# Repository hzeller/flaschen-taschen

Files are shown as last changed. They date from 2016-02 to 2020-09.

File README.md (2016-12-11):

Noisebridge Flaschen Taschen Project
====================================

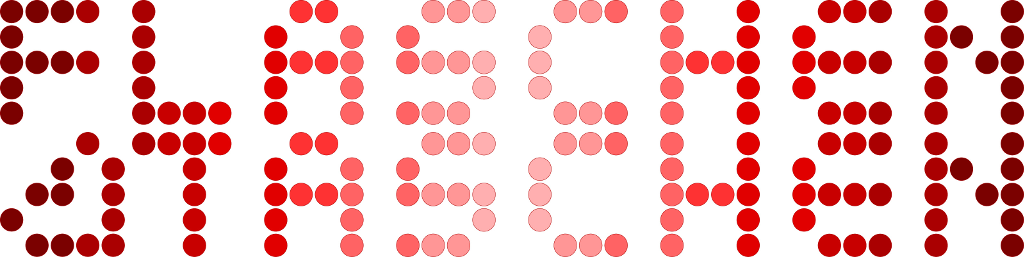
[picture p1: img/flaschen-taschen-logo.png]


Software and Raspberry Pi interface hardware for [FlaschenTaschen].

FlaschenTaschen is inspired by projects such as the [Muro de botellas]
or [MateLight]. A bunch of Noisebridgers have seen Mate Light in action
at [32c3] and got excited :)
So our Noisebridge interpretation of it has a German influenced name.

Unfortunately, in the US, bottle reuse is not at all a thing, so there
are no standardized crates with bottles you can buy.
So we use milk crates (which is a thing) and put common, clear 12oz (355ml)
bottles in (Mate, Corona,..) inside. Wrapped in aluminum foil, they
make nice pixels.

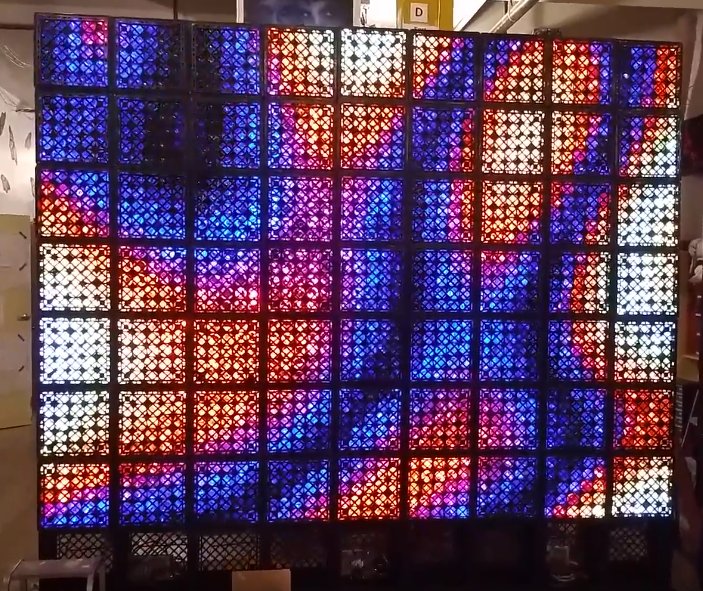
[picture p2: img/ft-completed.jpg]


How about watching [a movie](https://youtu.be/OEUFIpM10FE) ?

The set-up is 9 crates wide and 7 crates high for a total of
63 [crates (see wiring here)](./doc/wiring.md) with 25 'pixels' each
(this is what fits in our MakerFaire booth). 45x35 pixels or 1575 pixels total.
All operated by a Raspberry Pi that provides a [network API][protocols] to
update the display.

This is how it looks from the back:

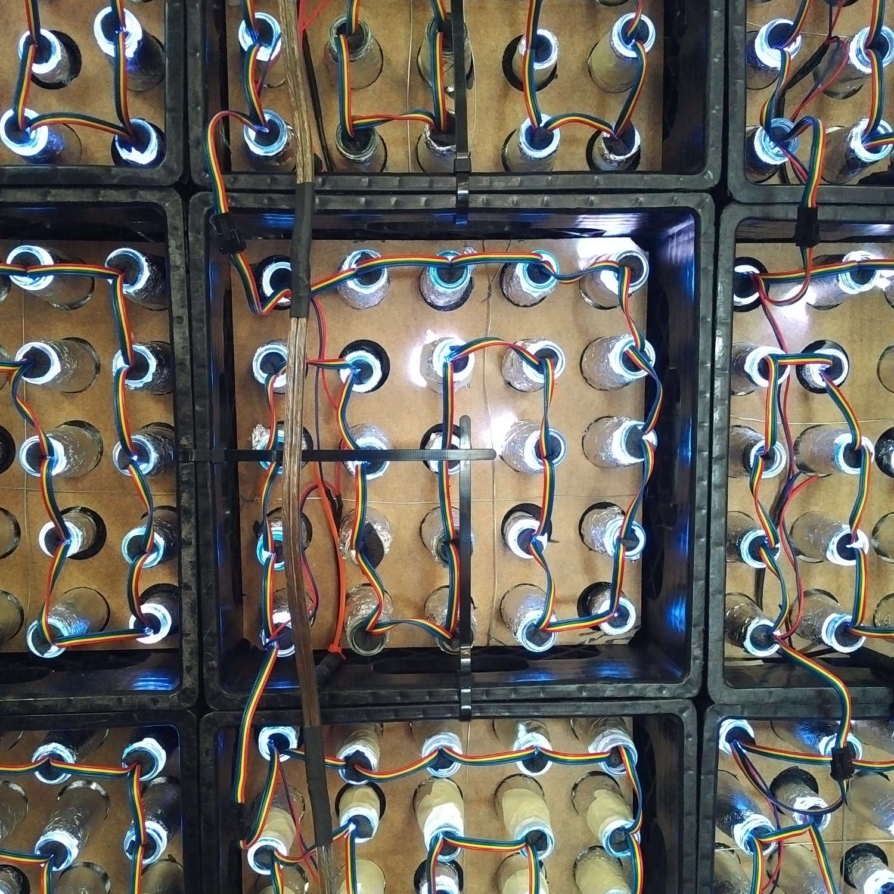
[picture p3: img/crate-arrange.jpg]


## Sending content to FlaschenTaschen

The [client](./client) directory contains some useful utilities such as
`send-text`, `send-image` or `send-video` that you might be interested in.

Also, the current development [VLC] natively supports the FlaschenTaschen
protocol if you want to send a video.

## Tutorial: start local server and create new clients

To develop visuals for the FlaschenTaschen display once it is ready, here you
can already play around writing software that updates the networked display.

#### 1. Check out the project

```bash
$ git clone --recursive https://github.com/hzeller/flaschen-taschen.git
$ cd flaschen-taschen
```

#### 2. Compile and run local server showing content in a Terminal

If you are not around Noisebridge to directly send images to the FlaschenTaschen
installation, then you can start your own FlaschenTaschen server that displays
the pixels as colored spaces in a terminal. Note, you need a fairly recent
terminal that can display 24 Bit color (Konsole can do that for a while, more
recent Gnome terminals as well. Also, newer xterms can do that as well. If you
are on a Mac, an iTerm2 version 3.x will work).

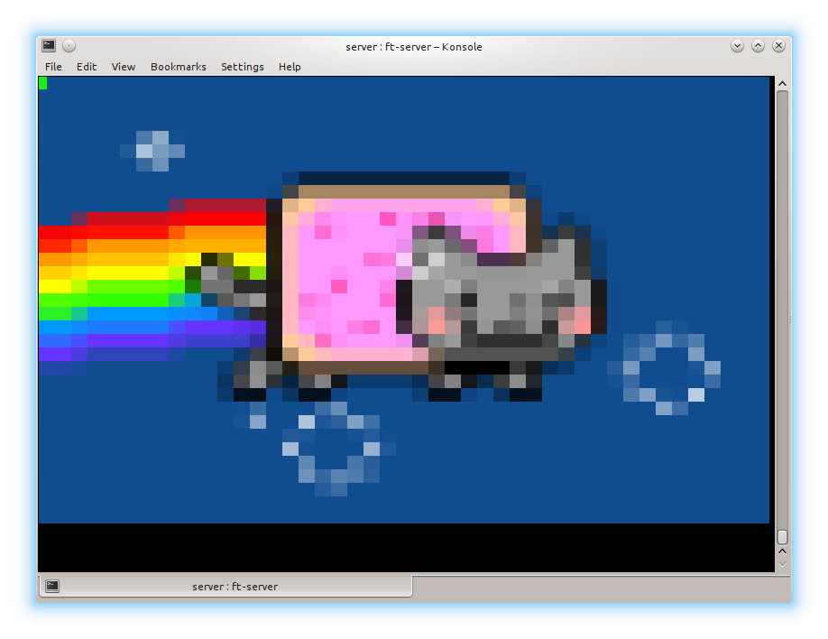
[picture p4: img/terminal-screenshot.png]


In one terminal, go to the [server/](./server) directory, compile the
terminal-based display and run it. Make sure to have it large enough to show
all pixels:

```
$ cd server
$ make FT_BACKEND=terminal
$ ./ft-server   #  this will now show a black 'screen'
```

(looks too big on screen ? Try adding the option `--hd-terminal`)

If you want to dig into details and understand the various server
implementations, check out the [server README](./server/README.md).

#### 3. Get started with the API
FlaschenTasachen provides a [network protocol](./doc/protocols.md), but there
are also client APIs available - the [api subdirectory](./api) is the best to
inspect here.

To get started with programming, go to the
[examples-api-use/](./examples-api-use) directory, compile the programs and
run it.

```
$ cd examples-api-use
$ make simple-animation
$ ./simple-animation localhost # <- network address of display.
```

Now go back to your terminal the `ft-server` is running and you'll see the
space-invaders animation!

Easiest to get started with the programming is
to read the [simple-example.cc](./examples-api-use/simple-example.cc) code,
then move on to [simple-animation.cc](./examples-api-use/simple-animation.cc).

If you want to implement the simple network protocol in another language
[check out the protocol description](./doc/protocols.md) or look at the
[C++ implementation](./api/lib/udp-flaschen-taschen.cc).

For some immediate fun, send a PPM image to your server. Since the server
already understands that format natively, you can unleash the usual
[netpbm] toolbox for image manipulation:

```
bash$ jpegtopnm myimage.jpg | stdbuf -o64k pnmscale -xysize 45 35 > /dev/udp/localhost/1337
```

For a tool that decodes images (including animated gifs), go to
the [client/](./client) sub-directory compile `send-image`
(`make send-image`, see
[Send-Image section in client/](./client/README.md#send-image) for needed
dependencies), then run
`./send-image -h localhost some-image.png` which reads images and
sends them to the FlaschenTaschen display.

## Related Software

There are various projects that create demos for F~T. Collecting links here.
Check out these repositories:

  * https://github.com/cgorringe/ft-demos Demos such as [plasma](./img/ft-completed.jpg), lines, quilt, ...
  * https://github.com/scottyallen/flaschenvnc VNC implementation:
   cast your screen to FlaschenTaschen
   ([like so](https://www.youtube.com/watch?v=s3pGp_Vf4Pk))
  * A [FlaschenTaschen VLC output](https://git.videolan.org/?p=vlc.git;a=commit;h=cf334f257868d20b6a6ce024994e84ba3e3448c3) by François Revol.
    It is already submitted upstream, but until it hits distributions, you have
    to [compile VLC from git](https://wiki.videolan.org/UnixCompile/). That VLC
    version is >= `3.0.0-git Vetinari`.
    Then `sudo make install ; sudo ldconfig` and run it like so:

   ```
    # Here, ft.noise is the hostname of the flaschen taschen display:
    $ vlc --vout flaschen --flaschen-display=ft.noise \
          --flaschen-width=45 --flaschen-height=35 \
          <video-filename-or-YouTube-URL>
   ```

## Connecting LED strips to the Pi

LED strips are controlled by a Raspberry Pi, connected via
a [custom level shifter](./hardware) for up to 16 strips
(of which we only need 9 for our installation right now).

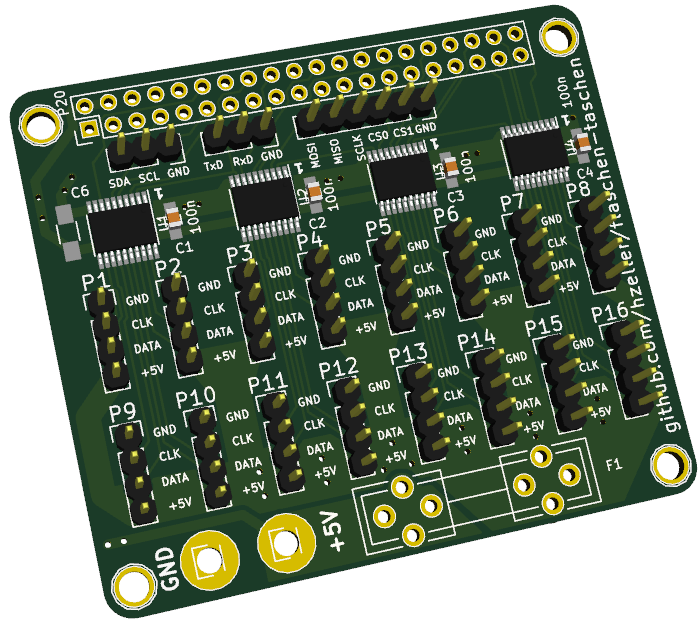
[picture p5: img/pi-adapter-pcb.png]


[FlaschenTaschen]: https://noisebridge.net/wiki/Flaschen_Taschen
[Muro de botellas]: http://www.zuloark.com/muro-de-botellas/
[MateLight]: https://github.com/jaseg/matelight
[RGB Matrix Adapter]: https://github.com/hzeller/rpi-rgb-led-matrix/tree/master/adapter/active-3
[32c3]: https://events.ccc.de/congress/2015/wiki/Static:Main_Page
[protocols]: ./doc/protocols.md
[netpbm]: http://netpbm.sourceforge.net/
[2025-video]: https://www.youtube.com/watch?v=hs8FoROzE4M
[7of9-video]: https://www.youtube.com/watch?v=Uc2-8ntcEpY
[VLC]: https://www.videolan.org/

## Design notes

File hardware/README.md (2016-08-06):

Hardware
========

## Connecting LED strips to the Pi

LED strips are controlled by a Raspberry Pi, connected via
a custom level shifter that first has been developed for FlaschenTaschen
but is now broken out as [separate Spixels PCB and library][spixels].

This adapter to the Raspberry Pi can support up to 16 SPI LED strips (e.g. WS2801 or APA102) at once.

&nbsp;&nbsp;&nbsp;&nbsp;&nbsp;


## Pi Mounting Plate

We have the Pi in a separate crate together with one of the power supplies. It is
held in place with zip-ties through the holes of the crate using this
laser-cut mounting plate. To be easily modifyable,
[it is written in PostScript](./pi-mounting-rig.ps) and can be converted to a
[DXF file](./pi-mounting-rig.dxf) (a typical input to laser cutters)
with the Makefile.

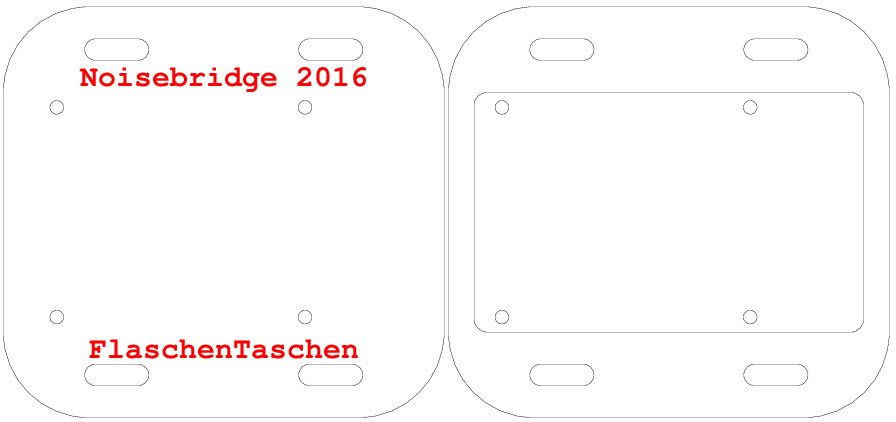
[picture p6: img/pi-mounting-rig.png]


[spixels-hardware]: https://github.com/hzeller/spixels/tree/master/hardware
[spixels]: http://spixels.org/

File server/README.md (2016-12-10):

Server implementation
=====================

The server implements the [network protocol](../doc/protocols.md) so that
it is easy to interface with the display over the network.

## Regular Flaschen Taschen server

For the actual Flaschen Taschen display, simply build with

```
  make FT_BACKEND=ft
```

(Note, this needs the http://spixels.org library, which is included as git
sub-module. So you have to `git clone --recursive` the flaschen-taschen repo).

These are the options

```
usage: ./ft-server [options]
Options:
        -D <width>x<height> : Output dimension. Default 45x35
        --layer-timeout <sec>: Layer timeout: clearing after non-activity (Default: 15)
        -d                  : Become daemon
```

```bash
 # Run as root.
 sudo ./ft-server -d
```

To change resolution and composition of the actual display, you have to
manually adapt the code in main.cc (look for `display.AddColumn()`) - to
choose type of LED strip and to which SPI port on the spixels hardware they
are connected to.

The server has to be started as root as it has to access and initialize the
GPIO pins, but it drops privileges to uid=daemon, gid=daemon after that is done.

Stopping ? Kill the hard way `sudo killall ft-server`.

*This assumes to be running on the Raspberry Pi* as it needs to access the
[GPIO pins](../hardware) to talk to the LED strips.



## Testing setups

If you are not at Noisebridge right now but want to hack on applications
that use the display, you can use different ways to visualize the output with
the following applications.

These test-setups allow to simulate the display in its full resolution
supporting the same protocol.

### Terminal

On any development machine with a somewhat decent terminal that allows for
24Bit [ANSI color][term-color] (konsole, xterm or gnome-terminal on Linux;
xterm/X11 or iTerm2 >= 3.0 on OS X), this `ft-server` allows to display the
result in a terminal.

```bash
  # Build with
  make FT_BACKEND=terminal
```

```bash
  # Then run (and optionally pass the desired resolution)
  ./ft-server -D45x35
```

This also has an option to have a more compact representation - the resolution
is twice as high which allows to display it on smaller terminals. However,
it depends a bit more on your terminal to properly display UTF-8 characters:

```bash
./ft-server -D45x35 --hd-terminal
```

Regular terminal             | With `--hd-terminal` Option   |
-----------------------------|-------------------------------|
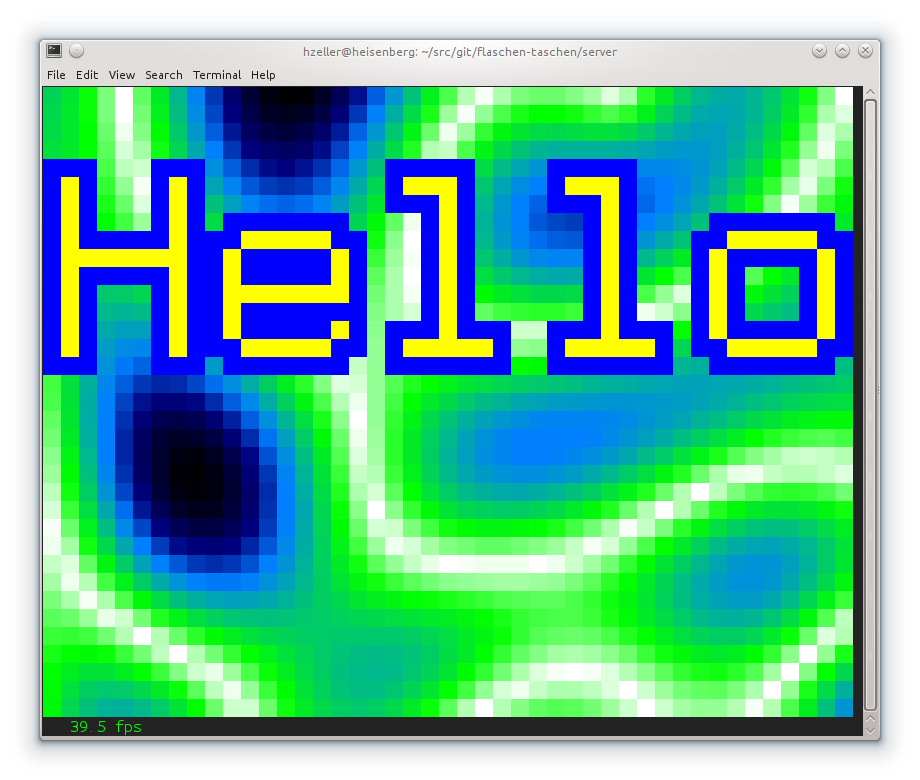
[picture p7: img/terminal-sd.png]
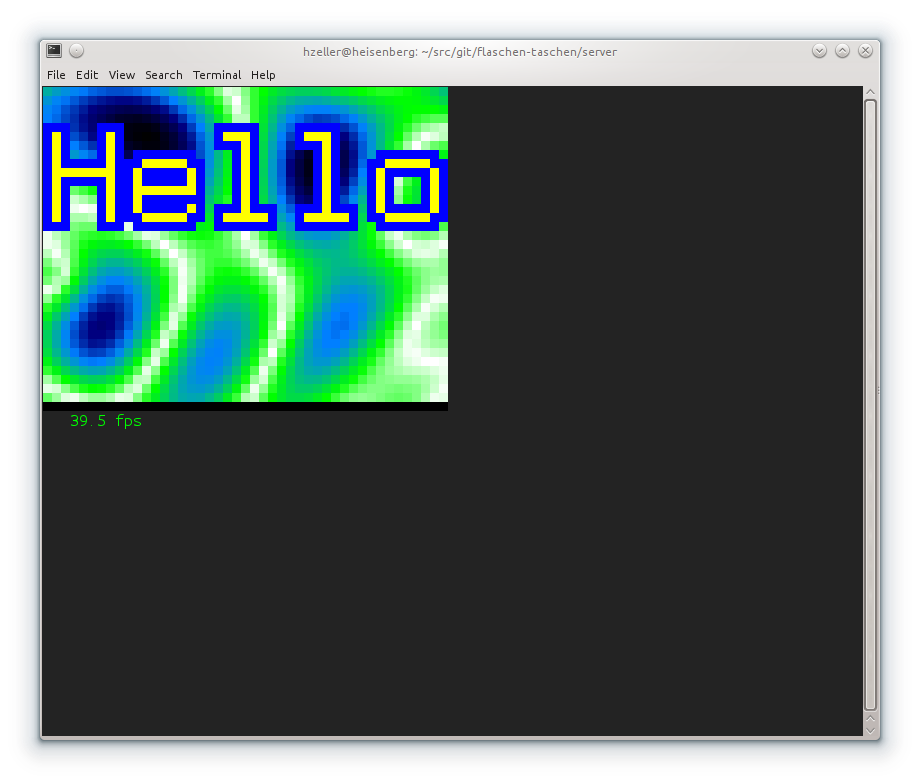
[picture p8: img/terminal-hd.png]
  |    |


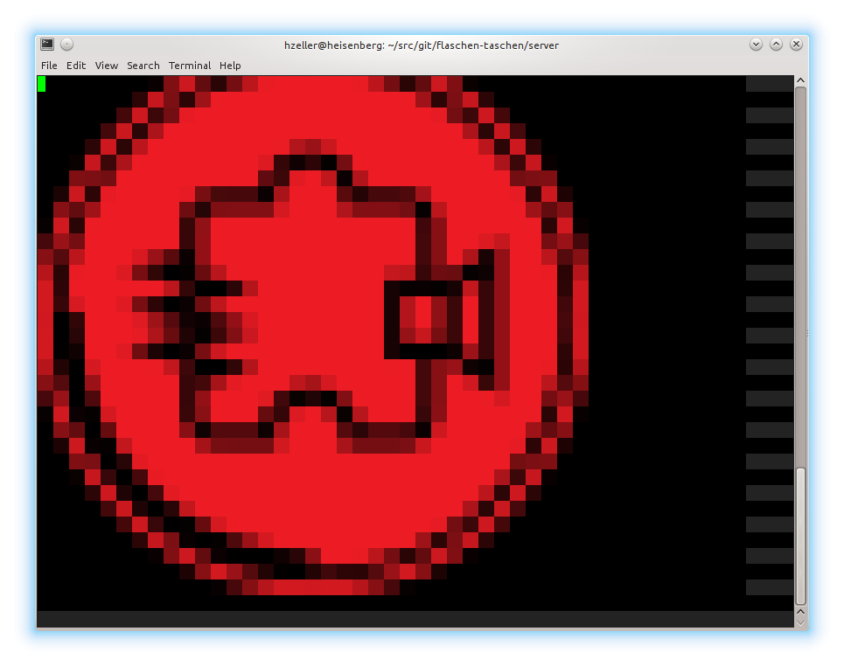
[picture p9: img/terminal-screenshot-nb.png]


### RGB Matrix Panel Display

If you have an [RGB matrix][rgb-matrix] connected to a Pi, you can run that
as Flaschen Taschen backend:

```bash
  make FT_BACKEND=rgb-matrix
```

Run it and pass the usual [rpi-rgb-led-matrix flags][led-flags]. Here, we have
a set-up with three parallel chains of 5 32x32 displays each
```bash
  sudo ./ft-server --led-chain=5 --led-parallel=3 --led-rows=32
```

If you pass the option `-d`, it will run as daemon in the background.

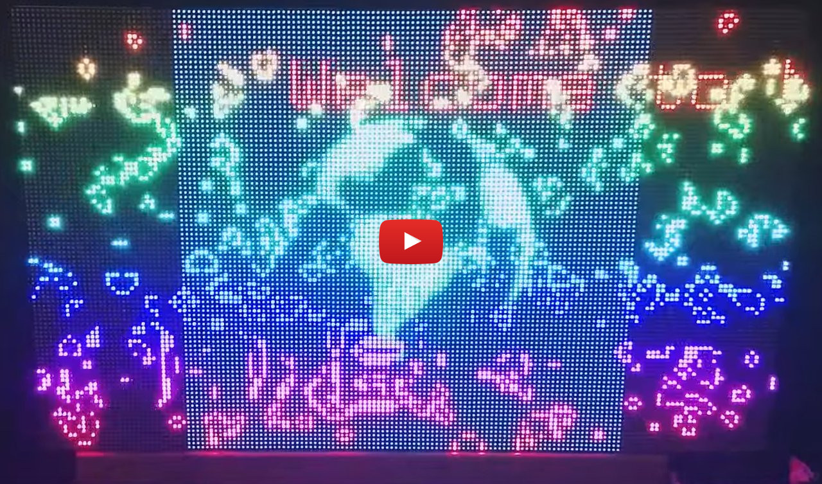
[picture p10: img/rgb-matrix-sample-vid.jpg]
RGB-MatrixImpl
[](https://www.youtube.com/watch?v=XeJBcNevuJE)
(this is 160x96 display with the `--led-chain=5 --led-parallel=3`).

This runs on a Raspberry Pi; see the
[documentation in the RGB-Matrix project][rgb-matrix]

[rgb-matrix]: https://github.com/hzeller/rpi-rgb-led-matrix
[ft-rgb-vid]: ../img/rgb-matrix-sample-vid.jpg
[term-color]: https://gist.github.com/XVilka/8346728
[led-flags]: https://github.com/hzeller/rpi-rgb-led-matrix#changing-parameters-via-command-line-flags

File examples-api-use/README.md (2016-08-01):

Getting started with the API
============================

This gives you some starting point to get started with the API.

### Network destination

Your programs connect to the display over the network. If you give `NULL`
as the location in the `OpenFlaschenTaschenSocket()` API call, the
hostname is determined from the environment variable `FT_DISPLAY`. If that
is empty, it falls back to the Noisebridge installation `ft.noise`.

So if you are working with a particular instance of FlaschenTaschen (e.g.
a [local terminal](../server/README.md#terminal)), just set the environment
variable for ease of playing.

```
export FT_DISPLAY=localhost
```

## Example Code

Coding content for FlaschenTaschen is trivial as you just need to send it UDP
packets with the content. Any language of your choice that supports networking
will do.

For C++, there is a simple implementation of such a 'client display', the
[simple-example.cc](./simple-example.cc) helps to get started.

```c++
#include "udp-flaschen-taschen.h"

#define DISPLAY_WIDTH  45
#define DISPLAY_HEIGHT 35

int main() {
    // Open socket and create our canvas.
    const int socket = OpenFlaschenTaschenSocket("ft.noise");  // hostname.
    UDPFlaschenTaschen canvas(socket, DISPLAY_WIDTH, DISPLAY_HEIGHT);

    const Color red(255, 0, 0);
    canvas.SetPixel(0, 0, red);              // Sample with color variable.
    canvas.SetPixel(5, 5, Color(0, 0, 255)); // or just use inline (here: blue).

    canvas.Send();                           // Send the framebuffer.
}
```

Next step, try a [simple-animation.cc](./simple-animation.cc)
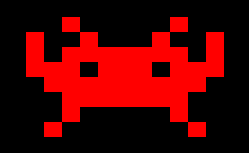
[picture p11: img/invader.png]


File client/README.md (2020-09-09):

Flaschen Taschen Clients
========================

Useful utilities to send content to the FlaschenTaschen installation.

This directory provides:
  * `send-text` binary, that prints a static or scrolling text.
  * `send-image` binary, that reads an arbitrary image (including
    animated *.gifs), scales it and sends to FlaschenTaschen.
  * `send-video` binary, that reads an arbitrary video, scales it and
    sends to FlaschenTaschen.

### Network destination

The clients connect to the display over the network. The
default hostname is pointing to the installation within Noisebridge
(currently `ft.noise`).

You can change that with commandline flags (e.g. `send-text`, `send-image`,
and `send-video` all have a `-h <host>` option) or via the environment
variable `FT_DISPLAY`.

So if you are working with a particular instance of FlaschenTaschen (e.g.
a [local terminal](../server/README.md#terminal)), just set the environment
variable for ease of playing.

```
export FT_DISPLAY=localhost
```

### UDP Size

The images are sent via UDP, and if the size does not fit in a single packet,
it will be split up into multiple stripes, so even large screens are supported.

The default assumed size of a maxium UDP packet is
65507 bytes (65535 - IP and UDP header), but note that on some operating
systems (notably OSX), the default allowed size is smaller. If you try to send
a large image or video and you get error messages, this might be the reason.

To fix: Either tell the client tool such as `send-video` to use a smaller
UDP size with the environment variable `FT_UDP_SIZE`. E.g.

```
FT_UDP_SIZE=8000 ./send-video -g320x200 ...
```

This will split the image into more stripes, so requies more network packets,
but it will work.

Or, if your operating sytem allows, set a larger limit. On OSX this would be:

```
sudo sysctl -w net.inet.udp.maxdgram=65535
```

## Send-Text

### Compile
```bash
make
```

### Use
```
usage: ./send-text [options] <TEXT>
Options:
        -g <width>x<height>[+<off_x>+<off_y>[+<layer>]] : Output geometry. Default 45x<font-height>+0+0+1
        -l <layer>      : Layer 0..15. Default 1 (note if also given in -g, then last counts)
        -h <host>       : Flaschen-Taschen display hostname.
        -f <fontfile>   : Path to *.bdf font file
        -s<ms>          : Scroll milliseconds per pixel (default 60). 0 for no-scroll.
        -O              : Only run once, don't scroll forever.
        -S<px>          : Letter spacing in pixels (default: 0)
        -c<RRGGBB>      : Text color as hex (default: FFFFFF)
        -b<RRGGBB>      : Background color as hex (default: 000000)
        -o<RRGGBB>      : Outline color as hex (default: no outline)
        -v              : Scroll text vertically
```

Sample
```bash
./send-text -f fonts/6x10.bdf "We ♥ Flaschen Taschen"

# Or coordinated horizontal and vertical messages
./send-text -h localhost "♥Flaschen" -f fonts/5x5.bdf -s 60 -g 45x35+0+15+3 & ./send-text -h localhost "Taschen " -f fonts/5x5.bdf  -v  -s 60 -g 45x35+20+0+2 && fg

# Or, how about showing the time
while : ; do sleep 1 ; ./send-text -f fonts/9x18.bdf -s0 `date +%H:%M` ; done
```

Text has a default layer of 1, so it is hovering above the background image.
If you don't want that, you can explicitly set it as last value in the geometry
specification.

If you add a `-o` color, then the font gets an outline of that given color,
which you can use to create a contrast for the font.
## Send-Image

### Compile
```bash
# Need some devel libs
sudo apt-get install libgraphicsmagick++-dev libwebp-dev
make send-image
```

### Use
```
usage: ./send-image [options] <image>
Options:
        -g <width>x<height>[+<off_x>+<off_y>[+<layer>]] : Output geometry. Default 20x20+0+0+0
        -l <layer>      : Layer 0..15. Default 0 (note if also given in -g, then last counts)
        -h <host>       : Flaschen-Taschen display hostname.
        -s[<ms>]        : Scroll horizontally (optionally: delay ms; default 60).
        -C              : Just clear given area and exit.
```

Essentially just send the FlaschenTaschen display an image over the network:

```
./send-image -g10x20+15+7 some-image.png
```

Image will be scaled to the given size (here 10x20) and shown
on the FlaschenTaschen display at the given offset (here 15 pixels x-offset,
7 pixels y-offset).

The program exits as soon as the image is sent unless it is an animated gif in
which case `send-image` keeps streaming until interrupted with `Ctrl-C`.

If you want to scroll a long image accross the display, use the `-s` option. In
this case, only the height is scaled to the display height and the image is
scrolled infinitely over width.

Let's try this with an example image:

```
./send-image -s ../img/flaschen-taschen-black.ppm
```

## Send-Video

This utility here is a simple video output without sound.

The upstream VLC [now has FlaschenTaschen support][vlc-commit] natively, so this
might be the better option these days (currently, you have to compile it
from source to get this bleeding edge).

### Compile
```bash
# Need some devel libs
sudo apt-get install libavcodec-dev libavformat-dev libswscale-dev
make send-video
```

### Use
```
usage: ./send-video [options] <video>
Options:
        -g <width>x<height>[+<off_x>+<off_y>[+<layer>]] : Output geometry. Default 20x20+0+0
        -h <host>          : Flaschen-Taschen display hostname.
        -l <layer>         : Layer 0..15. Default 0 (note if also given in -g, then last counts)
        -v                 : verbose.
```

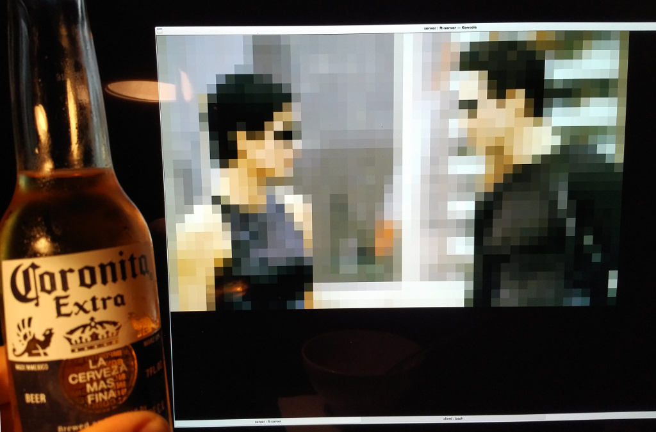
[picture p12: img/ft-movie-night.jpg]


[vlc-commit]: https://git.videolan.org/?p=vlc.git;a=commit;h=cf334f257868d20b6a6ce024994e84ba3e3448c3

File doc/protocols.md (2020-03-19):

Protocols
=========

To make it simple to illuminate the matrix, there is a simple network protocol
that allows to stream images to the FlaschenTaschen installation (we used to
support some other protocols natively, but they moved out to be done via a
dedicated bridge).

## Flaschen Taschen Protocol

Receives **UDP** packets with a raw [PPM file][ppm] (`P6`) on port 1337 in a
single datagram per image.
A ppm file has a simple text header followed by the binary RGB image data.

FlaschenTaschen has a special feature that allows you to choose the offset the
image is displayed on the screen in (x,y) direction and as a layer.

To provide this additional information without violating the PPM file standard,
there is a special comment that you can put in the header (because `#`-comments
are allowed in the PPM header) that describe the offset of the image on the
display in X, Y and Z-direction (=layer).

The comment must start with exactly **`#FT:`**. In the following example,
a 10x10 image is sent with the (x,y) offset of (5,8), the layer (z-offset)
is 13; the full UDP packet combining header and data looks like this:

------

```
P6     # PPM binary Portable PixMap magic number
10 10  # width height (decimal, number in ASCII)
#FT: 5 8 13
255    # values per color (fixed). After newline, 10 * 10 * 3 bytes RGB data follows
```
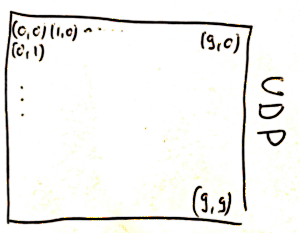
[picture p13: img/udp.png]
 (300 bytes RGB data)<br/>

------

(the header is followed by the binary image data, three bytes per pixel RGB, so in this case 10x10x3 = 300 bytes)

There is an alternative way to provide the offset by appending it at the _end_ of
the image data in a similar format like the header because that is sometimes
easier to do depending on your implementation.
Appending it at the end makes it also backward compatible with
standard PPM (as PPM just ignores additional data at the end).

Here the same 10x10 image with (header + data + optional footer). The footer is
similar formatted like the header: decimal numbers, separated by space).
End-of-line comments in the header/footer are allowed with `#` character. So
the full UDP packet combining header, data and footer looks like this:

------

```
P6     # PPM binary Portable PixMap magic number
10 10  # width height (decimal, number in ASCII)
255    # values per color (fixed). After newline, 10 * 10 * 3 bytes RGB data follows
```
 (300 bytes RGB data)<br/>
```
5      # optional x offset
8      # optional y offset
13     # optional z offset.
```

------

The optional offset determines where the image is displayed on the
Flaschen Taschen display relative to the top left corner (provided in the
[remote Flaschen Taschen class][cpp-client-api] as a `SetOffset(x, y, z)` method).

### Offsets, how do they work ?

The **(x,y) offset** allows to place an image at an arbitrary position on the
screen - good for animations or having non-overlapping areas on the screen.

The **z offset** represents a **layer** above the background. Zero is the
background image, layers above that are overlaying content if there is a
color set (black
in layers not the background are regarded transparent).
That way, it is possible to write games simply (consider typical arcade games
with slow moving background, a little faster moving middelground and a fast
moving character in the front. This allows for full screen sprites essentially).

Or you can overlay, say a message over the currently running content.
The nice thing is is that you don't need to know what the current background
is - a fully networked compositing display essentially :)
This allows display access for independent people on the network, right the
way we use it at Noisebridge.

Note: layers above the background (z=0) will auomatically turn transparent again
if they stick around for a while without being updated (that is
the `--layer-timeout` flag to the server).

### Send images right from the command-line

Since the server accepts a standard PPM format, sending an image is as
simple as this; you can make use of the convenient pnm-tools right from your
command line, how cool is that ?

```bash
# This works in the bash shell providing the pseudo-files /dev/udp/host/port
bash$ jpegtopnm color.jpg | stdbuf -o64k pnmscale -xysize 20 20 > /dev/udp/ft.noise/1337
# replace 'ft.noise' with 'localhost' if you have
# a locally running server, e.g. terminal based
```

If you're not using `bash`, then the `/dev/udp/...` path won't work, then
you can use the network-swiss army knife `socat`
```
$ jpegtopnm color.jpg | stdbuf -o64k pnmscale -xysize 20 20 | socat -b64000 STDIO UDP-SENDTO:ft.noise:1337
```

#### Implementations
You find some tools in the [`client/` directory](../client) to directly send
content to the server.

For the API level, there are a couple APIs provided in the [`api/`](../api)
directory, that let's you get right into it:

 * [C++ API][cpp-client-api]
 * [Python API][py-client-api]

For instance, the [FlaschenTaschen demos] by Carl are using the C++ API.

There is a [FlaschenTaschen VNC implementation](https://github.com/scottyallen/flaschenvnc) by Scotty. Scotty also wrote a server implementation for the ESP8266
that runs LED strips in the [Noise Square Table] and the Noisebridge library
shelves.

To watch videos, there is now a [FlaschenTaschen VLC output](https://git.videolan.org/?p=vlc.git;a=commit;h=cf334f257868d20b6a6ce024994e84ba3e3448c3) by François Revol available (until it hits distributions, you have to [compile VLC from git](https://wiki.videolan.org/UnixCompile/)).

### Network address of Installations
Within Noisebridge, the hostname of the large 45x35 pixel installation
is `ft.noise`.
The smaller 25x20 display is called `ftkleine.noise`.
Then there are pixel strip implementations for
the bookshelves with hostname `bookcase.noise` and
the [Noise Square Table], hostname `square.noise`.

#### Notes
For huge displays (more than 21k pixels) we run into UDP packet size limit of
roughly 64k. In that case, you need to send several tiles of the image and use
the offset feature to place them on the screen.
(We might consider adding a TCP protocol for these cases).

Note, this is _not_ an issue with the large FlaschenTaschen installation at
Noisebridge (1575 pixels) as it requires less than 8% of the UDP limit. But it
could be an issue with huge assemblies using an
[RGB Matrix](../server#rgb-matrix-panel-display) with many small LEDs.

[ppm]: http://netpbm.sourceforge.net/doc/ppm.html
[cpp-client-api]: ../api/include/udp-flaschen-taschen.h
[py-client-api]: ../api/python/flaschen.py
[Noise Square Table]: https://noisebridge.net/wiki/Noise_Square_Table
[FlaschenTaschen demos]: https://github.com/cgorringe/ft-demos

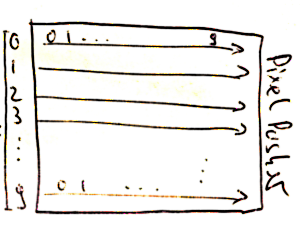
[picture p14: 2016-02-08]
img/pixelpusher.png

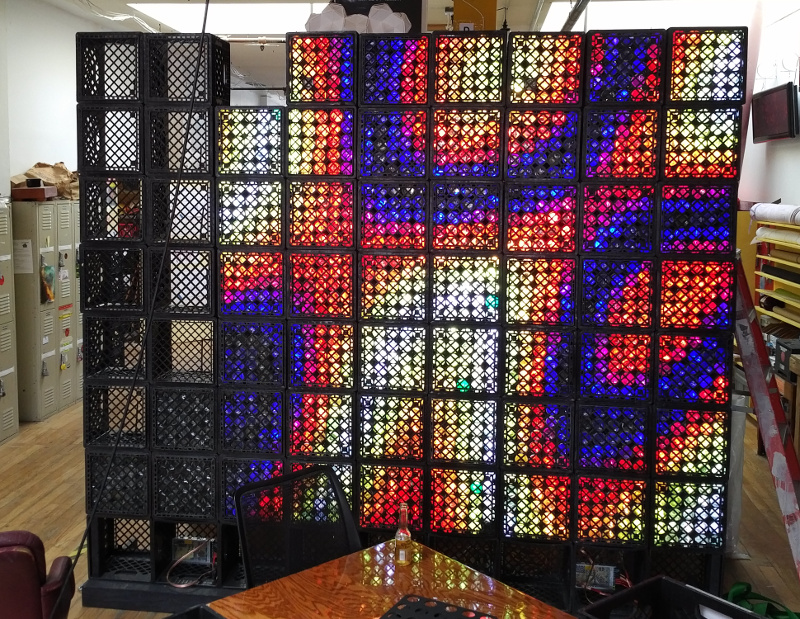
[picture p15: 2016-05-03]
img/ft-work-in-progress.jpg

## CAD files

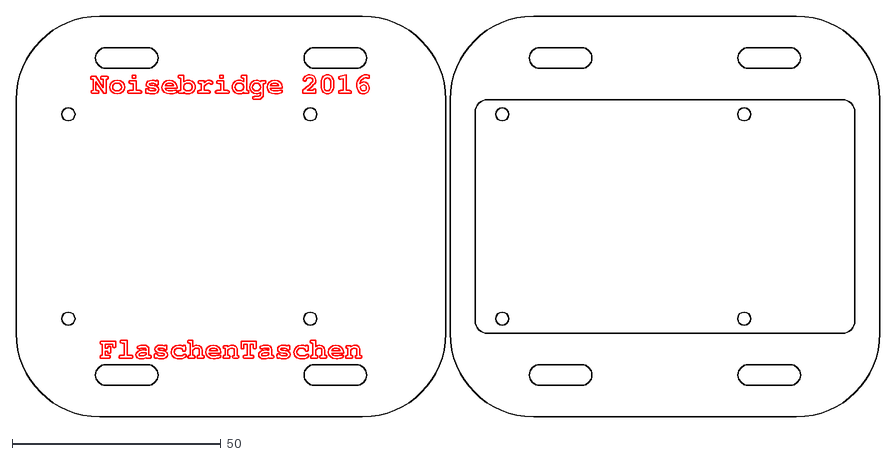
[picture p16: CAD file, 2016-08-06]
hardware/pi-mounting-rig.dxf
207.0 x 96.0

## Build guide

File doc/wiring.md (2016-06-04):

Wiring the crate
================

Looking from the back, the crate has the incoming data on the left bottom,
exit top left. We also have one power barrel connector on each crate, as well on the bottom
left.

The wiring is in a zig-zag pattern through the crate such that we reach the goal having
the incoming/outgoing cables at the right place.

## Tracing through the Crate

Here some schematic representation - Stars represent the bottle-necks, the arrows
the wiring between them. You can retrace that in the picture below.

```
  |  outgoing. 4-position female connector.
+-|---------------------+
| * <- * <- * <- * <- * |
|                     ^ |
| * -> *    * -> *    * |
| ^    v    ^    v    ^ |
| *    *    *    *    * |
| ^    v    ^    v    ^ |
| *    *    *    *    * |
| ^    v    ^    v    ^ |
| *    * -> *    * -> * |
+-|---------------------+
  |
  | Incoming. 4 position male connector.
```

## The power connection

The LED power inputs are long loose cables on both ends of the strip that we
combine and solder to a barrel-jack receptacle pig-tail, see image below.
Make sure to thread the wires from the LED _under_ the data wiring between the bottles.

As a preparation for soldering, the pigtail needs to be shortened by about 10cm (4 inches),
the LED power cables roughly by 6cm (2.5 inches) to not have too much slack. When removing outer
insulation from the pig-tail, make sure to not injure the insulation of the inner cables.

You don't have to unfold the whole LED strip or put it in the box to solder on the
power pigtail. Just do the whole process directly on the bundle of LEDs, it saves a lot of
time. The below images have the crate in the background for illustration purposes.

Uninsulate about 1 inch of the wires going to the LEDs and twist together the red
and blue ones separately. Put a ~1 inch of heat-shrink tubing up each pair now, so that we don't
forget that - move it up enough that it won't heat up while we solder.

Put about 1.5 inches of heat-shrink tubing wide enough to fit around the pigtail insulation now
as well - we need that later to tie everything together.

Now, uninsulate as well the wires on the pigtail about 1 inch. Now make a
[Lineman splice] with the corresponding wire-pair from the
LEDs (colors: red with red, white (pigtail) with blue (LED)). Solder the splice (it giving the
twisting, the whole length of the splice is now probably about 1/2 inch).

(If anything: remember the [Lineman splice] - it is a very useful skill!).

Move the heat-shrink that we have parked on the LED cables to each connection and shrink with
quick movements with a lighter (or, if that is not at hand, with the hot-air gun).

  Splice before solder.  |  Heat Shrunk.           | Heat Shrink overall.      | Done.
-------------------------|-------------------------|---------------------------|--------------------------|
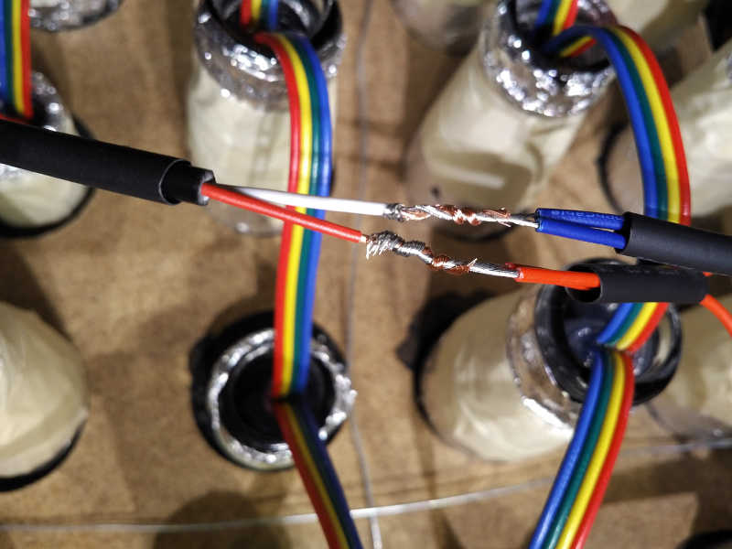
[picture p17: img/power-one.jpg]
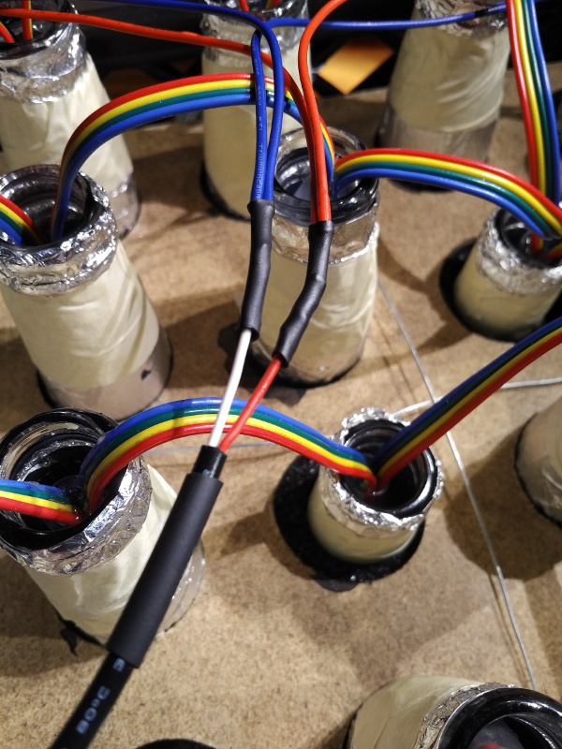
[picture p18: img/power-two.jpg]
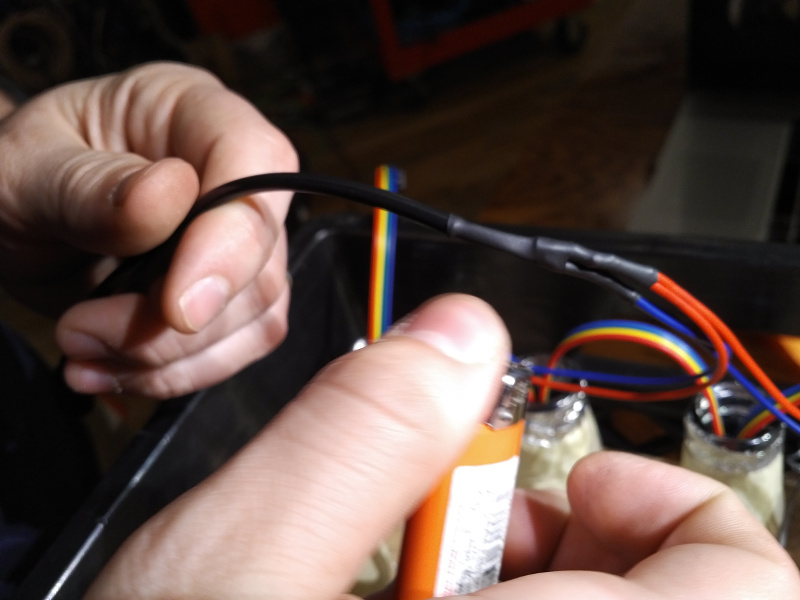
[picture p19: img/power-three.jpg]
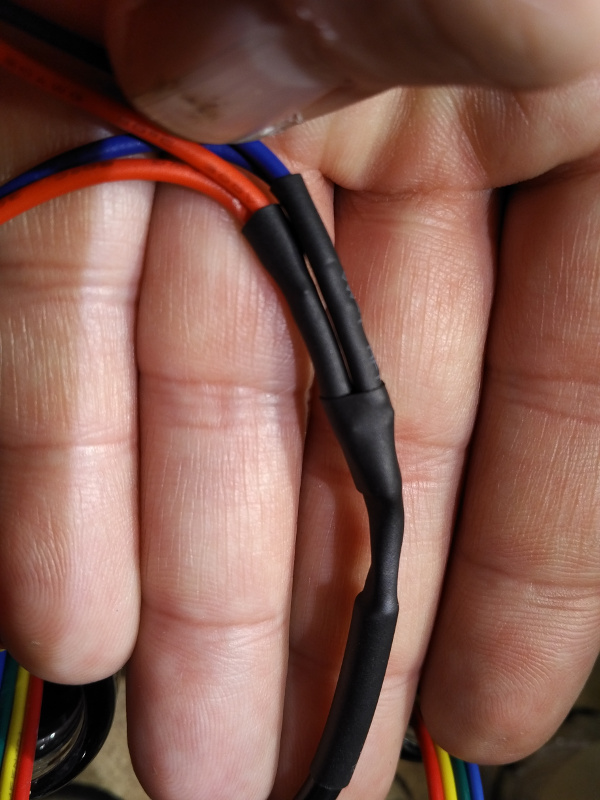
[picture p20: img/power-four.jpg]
||||

Let it cool so that it is hand-warm again. Then move the heat-shrink parked on the pigtail
up so that it squeezes the other heat-shrunk connection together and on the other end covers the
outer insulation of the pigtail. Shrink that. Now we have a sturdy connection.

(Use the heat shrink of which we have large rolls in the electronic area on the
left side on the shelf).

The Pigtail should be cable-tied to the crate for now. Later on we might want
a stress relief flap screwed to the wood ?

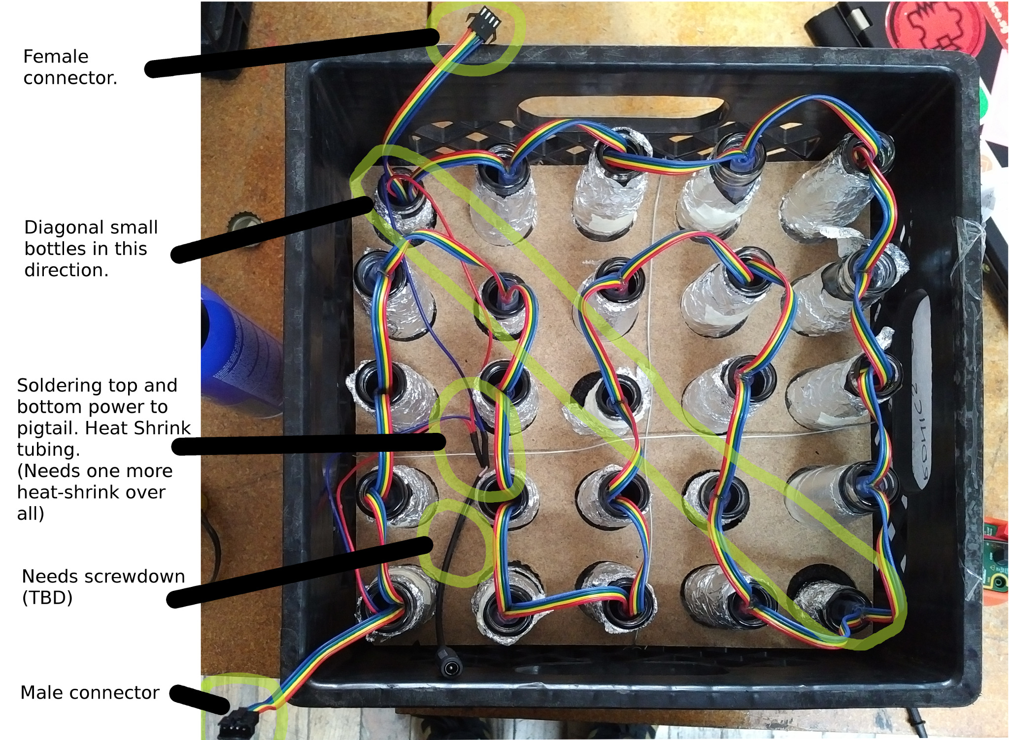
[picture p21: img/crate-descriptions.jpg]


## The Result

This is how it looks when it is all connected within the final display: the
data connectors are chained from crate to crate. A separate spine with power
is supplying 5V to each crate individually.

Due to the cabeling, this is also fault tolerant: if power gets disconnected
on one crate, it will be powered, through GND/+5V line of the data cables, from
the two adjacent crates above and below.

All data and power connectors run up on the left side, so it is very simple to
stack crates without much thinking when moving the installation. The cable-ties
to secure the crates are the reusable kind.



[Lineman splice]: http://makezine.com/2012/02/28/how-to-splice-wire-to-nasa-standards/

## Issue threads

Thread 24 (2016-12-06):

Problem flaschen taschen with RGB matrix

ffqqtv, 2016-12-06:
Thanks about flaschen-taschen library ! it is great . Now , i have 9 module RGB matrix ( 64x32) connecting Pi 3 , I am using flaschen-taschen library to send image and video , but I do not know how to adjust --led-rows=<rows> --led-chain=<chained> --led-parallel=<parallel> --led-brightness=<percent> -C
https://youtu.be/XVejSbku9Nc

hzeller, 2016-12-10:
You have 6 LED panels in a row, so you want --led-chain=6. The 32x32 pixel will already work with the default settings (--led-rows=32 --led-parallel=1).

hzeller, 2016-12-10:
Also, until a few minutes ago, you also had to explicitly make sure to set the geometry on the server side with `-D64x32`. If you do a fresh `git pull`, this will now be automatic.

Closed 2017-07-30.

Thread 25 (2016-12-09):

extending the chain lenth

alexdisoza007, 2016-12-09:
hi

Great job !.. I'm working  on this project and not able to extend the chain length, (in  rpi-rgb-led-matrix used -c option to extend the chain length) , how to extend the chain length in this project.

Thanks
Alex

hzeller, 2016-12-10:
You mean you are using it with the led matrix ? Try `--led-chain` instead of `-c`

alexdisoza007, 2016-12-10:
Hi,
I tired with this command `./send-text -h localhost --led-chain=2 --led-rows=32 -f fonts/9x18.bdf "flaschen taschen"` but this error popup `./send-text:` invalid option -- '-'`

Thanks
Alex

hzeller, 2016-12-10:
the `--led-chain` you need to give on the **server**, as that is running the LED. That server then provides the display you send stuff with clients such as send-text.

The send-text only needs the right size of your display  with `-g192x32` for instance.

alexdisoza007, 2016-12-10:
Hi.
Its working , but it is only using only 48x32, but mine is 64x32.

hzeller, 2016-12-10:
Did you make sure to set the resolution in the client program so that it knows how big of a framebuffer to send ?
```
 ./send-text -g64x32 ...
```

alexdisoza007, 2016-12-10:
Yes, its  is -g64x32 only , `./send-image -g64x32 -h localhost ../img/spixels-video.jpg`.

alexdisoza007, 2016-12-10:
yes , its only -g64x32, ./send-image -g64x32 -h localhost `../img/spixels-video.jpg`
[https://www.youtube.com/watch?v=MgZdQJVqTzA&feature=youtu.be](url)

alexdisoza007, 2016-12-10:
Hi,
I got out of that issue by using `-D 64x32` on server side. Thanks for your support.

Thanks
Alex

Closed 2016-12-10.

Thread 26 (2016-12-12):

Not able to display small letters in newly committed code

alexdisoza007, 2016-12-12:
Hi,
In text example program , If I give text in small letters it is displaying in capital letters. Is their any other ways to display small letters?
If I provide more than one text by pipe lining with different offset i am getting flickering problem ,Is it is due to power issue ? please do find the attach  link
[https://www.youtube.com/watch?v=iqwcEEiQQgU&feature=youtu.be](url)

Thanks
Alex

hzeller, 2017-07-30:
I suspect you used a font that didn't have lower case characters ?

If you send multiple text on the same layer, they will be 'fighting' each other as you replace the previous pixels with the new pixels. Try sending them on a different layers.

Closed 2017-08-22.

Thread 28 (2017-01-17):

Issue compiling

crablab, 2017-01-17:
```
`ft-thread.o: In function `ft::Mutex::WaitOnWithTimeout(pthread_cond_t*, int)':
ft-thread.cc:(.text+0x290): undefined reference to `clock_gettime'
collect2: ld returned 1 exit status
Makefile:76: recipe for target 'ft-server' failed
make: *** [ft-server] Error 1
`
```

hzeller, 2017-01-17:
What is the Linux distribution you're compiling it on ? On older installations, you might need to add `-lrt`  to the `LDFLAGS+=-lpthread` line in the Makefile.

crablab, 2017-01-17:
Ubuntu 16.10
I'll try that

hzeller, 2017-07-30:
I suspect that worked out ?

crablab, 2017-07-30:
I think it did, thanks!

Closed 2017-07-30.

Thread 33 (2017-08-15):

flaschen-taschen Full screen Image

beikimajid, 2017-08-15:
According to https://github.com/hzeller/rpi-rgb-led-matrix/issues/372,
(My image and my led screen are  384x96)

I use (**./ft-server**) and  -g  parameter (./send-image -g384x**96**+0+0 some-image.png)
_Result :         Attempting to send image larger than fits in a UDP packet (110623 > 65507 bytes)_

I use (**./ft-server**) and  -g  parameter (./send-image -g384x**54**+0+0 some-image.png)
_Result :        It does not show anything._

Then I use (**./ft-server --led-chian=36**) and (./ft-server --led-chian=36 -D 384x**54** )
_Result :        The image became displayed but But not in full screen_

My problem is on the height. (96 pixel height >>> error)
What is the problem and How do I get the fullscreen image?

hzeller, 2017-08-15:
384 * 96 pixels is 110592 bytes, but a UDP packet size limit is 64k.

So just send it in two halfs ( `-g192x96+0+0` and `-g192x96+192+0`) or write a network protocol that uses TCP.

beikimajid, 2017-08-15:
Do you mean to split the Image into two parts? How?

hzeller, 2017-08-15:
Any image processing tool will do.

beikimajid, 2017-08-15:
How about video file instead of image?

hzeller, 2017-08-15:
I honestly don't understand why you make your life so complicated. From what I can tell from the flood of messages, you want to show some animation on some fairly large display and you spent the last couple of days trying so.

Why don't you just use the rpi-rgb-led-matrix and write a program that does that with double-buffering. Or implement a compressed stream. It will take you an afternoon to implement and you're done.

beikimajid, 2017-08-15:
I'm really sorry to be so annoying you.
I use util(led-image-viewer) And just as you said I want to show some animation on some fairly large display.
Can you help me out which part of the code I start with?
I'm sorry again

hzeller, 2017-08-15:
I would start by just using the `-O` option to write the preprocessed stream and then play that stream. The output file might be large, but storage is cheap so it might not really be a big deal. Make sure to have a sufficiently good quality fast SD card for that, and you can easily play this size animation with more than 100fps.

If the file is too large, then consider implementing an on-the-fly compression and uncompression in `content-streamer.{h.cc}` and use that in led-image-viewer. There might be some low-hanging fruit in just using e.g. snappy to compress each frame; or you can do things like taking differentials and compress these which typically creates better compression ratio unless the animation is very busy.

You also can just _not_ do the preprocessing but just take the RGB images and just set the pixels directly and then just implement simple double buffering. This is what the `video-viewer` is doing internally, you can get some inspiration from there (you could also use the `video-viewer` directly, but make sure to have the size of your video already the size of the output, otherwise flickering will be seen. Also, videos have more compression artifacts, so if this is for line-art, it will not work well).

Using double-buffering in the led-image-viewer will actually simplify it, but it will constantly use CPU to fill frames at runtime, and this is somewhat limited around 3-4 Megapixels/s (on a Raspberry Pi3), so with your size panel, this will use a full core to roughly get 80-100fps (which might be ok, the Raspberry Pi 3 has 4 cores, one of which is reserved for the display output).

Closed 2017-08-15.

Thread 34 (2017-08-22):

Regarding client code

noorabrar1, 2017-08-22:
I wanted to run client code from my laptop(ubuntu), and server as Raspberry pi 3, as in raspbery both client and server code working fine.
but in system i'm getting error while making client file.
error is:
/usr/include/c++/5/bits/c++0x_warning.h:32:2: error: #error This file requires compiler and library support for the ISO C++ 2011 standard. This support must be enabled with the -std=c++11 or -std=gnu++11 compiler options.
 #error This file requires compiler and library support \

can you please help me out of this

hzeller, 2017-08-22:
Can you do a fresh git pull and try again ?

noorabrar1, 2017-08-23:
Thanks for replay sir.. i cloned and tried for 3 times.. same result,... actually i am new here, i dot know hot to pull, is that same as clone..  please can you guide me on this...

hzeller, 2017-08-23:
`git pull` you do in the directory that you already had cloned to get the latest version.
`git clone` is what you do to do a fresh checkout.

So if your error was in the bdf-font before, then with the current version you can't get the same error message, because the file in question is not even included anymore. If you get another error, please provide a little bit more context (e.g. the name of the file that was compiled and generated the error)

noorabrar1, 2017-08-23:
hello sir,

Thanks for info, got some knowledge.. zero errors, it worked, but only sent-text file appeared.. other image and video file missing from client folder... anyhow i wanted only send-text file.. thanks for help sir.  and final question y those two file disappeared?????

Closed 2017-08-22.

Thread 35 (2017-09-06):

Diffrent scan rates

noorabrar1, 2017-09-06:
Hello sir,

I am new to git hub..

I'm working on HUB75 for a project, the connectivity with pi3, and i am using your client server code.
using 3 different scan rate HUB75 board each four 32x32 panel connected in series and parallel

code:

Server: sudo ./ft-server --led-parallel=2 --led-rows=64 -D64x64 --led-chain=2

Client: sudo ./send-text -g64X64+0-0+1 -h localhost "hello" -f fonts/6x12.bdf -c ff0000

    HUB75-P5-16S-32x32-B0 consist of ABCD data lines (Works absolutely fine with series and parallel connections)

    HUB75-P2.5-32S-64X64 consist of additional E data line, wiring is properly connected(Not working properly, some set of upper led wont glow even i made correction -D128x128)

    HUB75-P5-8S-32x32 ABC data lines(Not working properly, multiple prints appear )

Please help me to set different scan rate. is there any other libraries has to downloaded or any other arguments i need to give.. ??

Sorry for posting in that issue i thought it was similar

hzeller, 2017-09-06:
see https://github.com/hzeller/rpi-rgb-led-matrix/issues/390

Closed 2018-03-26.

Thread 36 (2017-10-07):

-L (large display) option for ft-server

marcobrianza, 2017-10-07:
Hello, and thank you for this great project.
I'm testing some configuration with Processing sending images to ft-server: it works :-)
I have seen that ft-server, differently from the other demos, is missing the -L option for U turn display configuration.
Is it a feature you can add ?
Thank you
Marco

hzeller, 2018-03-26:
I've updated the matrix library, so you can now use the [`--led-pixel-mapper="U-mapper"`](https://github.com/hzeller/rpi-rgb-led-matrix/tree/master/examples-api-use#u-mapper)  feature.

marcobrianza, 2018-03-26:
thank you!, I'll try it as soon as possible.

Closed 2018-03-26.

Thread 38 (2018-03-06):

how to create own Image ppm file in flaschen -taschen

ManjunathRN, 2018-03-06:
Hello sir,
I am new to git hub
I'm working on HUB75 for a project with Pi, and i am using your client server code with 1:16s scan rate , HUB75 board each four 32x32 panel connected in series and parallel .I have did different  types of text scrolling and  yours  ppm files as included in this flaschen -taschen but i don't know how to create own ppm image file and run it in this F/T protocol .please help  me actually i am new one to this
Thank you

hzeller, 2018-03-26:
Please read the [protocol documentation](https://github.com/hzeller/flaschen-taschen/blob/master/doc/protocols.md#flaschen-taschen-protocol). The PPM format is the simplest image format essentially, just all the pixels in binary format one after another.

If you want to send images, just store them as PPM format in your favorite image editor.

If you want to get started programming things, you don't even need to assemble that yourself; you can use the [C++ API](https://github.com/hzeller/flaschen-taschen/tree/master/api/include) or [Python API](https://github.com/hzeller/flaschen-taschen/tree/master/api/python).

Closed 2018-03-26.

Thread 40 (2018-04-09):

P2.5-64X64-32S

HummingBuddha, 2018-04-09:
Hello Hzeller

I am using a P2.5 64x64 32S. Have used both the rpi-rgb as well flaschen-taschen commands viz..

RGB - sudo ./demo -D 1 runtext.ppm --led-chain=1 --led-cols=64 --led-rows=64 --led-pwm-bits=1 --led-pwm-lsb-nanoseconds 1000 --led-multiplexing=1
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

F&T - @ Server - sudo ./ft-server --d-chain=1 --led-rows=64 --led-multiplexing=1 D64x64  --led-pwm-bits=1
           @ Client - ./send-text -h localhost "999" -f fonts/10x20.bdf -s 0 -g 64x64+0+0
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

I am facing two issues here -
1 - I am not getting full display of the ppm or even the text. I have attached the images for ur ref..
2 - The text colours are not changing other than RGB & W. If I give ./send-text -h localhost "999" -f fonts/10x20.bdf -s 0 -g 64x64+0+0 -c FF8800, the text colour is displayed as red rather than some what amber one. It holds good for other 2 colours also, if i give 00f8bb which has to be
a somewhat close mint colour it displays a green.

Hope you understood my queries. I am posting this in F&T as i am more towardly going to use F&T.

Thanks.

hzeller, 2018-04-09:
1) Did you connect the `E`address line ?
2) You choose `--led-pwm-bits=1`, so you only get one bit per RGB color as requested. If you want grayscale, leave it at its default or at least choose values > 1.

HummingBuddha, 2018-04-10:
1 - E address line is connected.

2  - Choose that as --led-pwm-bits=1 as in my previous attempt i had too much of shaky/distortion in        
my displayed text.

**F&T**
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

_Server_ $ sudo ./ft-server --led-rows=64 --led-cols=128 D128x64 --led-parallel=2

_Client_ $ ./send-text -h localhost "Flaschen & Taschen" -f fonts/10x20.bdf -s 20 -g 128x64+0+30 -c FFBB00

**RGB**
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

_For_ -  sudo ./demo -D 1 runtext.ppm --led-rows=64 --led-cols=128 --led-parallel=2 --led-pwm-bits=11

For default PWM I am getting a distorted image wherein for PWM as 1, I am getting better image with not so crisp colour rendering.

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

_For_ -  sudo ./demo -D 1 runtext.ppm --led-rows=64 --led-cols=128 --led-parallel=2 --led-pwm-bits=1

Texts are working fine now, but the text is not crisp and clear and colour rendering is not fine. Until display is set, the colours cant be visualized as it is to be. These issues cropped in P5 so started to try on 2.5 but in vain. The previous posted cmds  worked great on P5 but suddenly it started to react differently so started to try on P2.5, but its the same.
Pls let me know any other nuances has to be taken care of. Thanks for your patiences.

HummingBuddha, 2018-04-10:
The P5 is a snake config so I have used --led-mux=1.. and pls do say whats the issue in this P5
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

**Server**
sudo ./ft-server --led-chain=2 --led-parallel=2 --led-rows=32 --led-multiplexing=1 D64x64

**Client**
./send-text -h localhost "RedGreebBlue" -f fonts/10x20.bdf -s 0 -g 64x64+64+10+1|./send-text -h localhost "Flaschen&Taschen" -f fonts/10x20.bdf -s 0 -g 64x64+64-20+2 -c ff8800

If PWM bits are default I have an issue of too much flicker, if I use PWM as 1 the flicker drastically reduces but colours are not rendered only RGB&W is rendered..

Thanks

hzeller, 2018-04-10:
Washed out display usually happens if you have too long cables (> 20cm) and/or [no logic level conversion (from 3.3->5V)](https://github.com/hzeller/rpi-rgb-led-matrix#logic-level-voltage-not-sufficient).

It can also be, that your matrix is too slow, in which case you want to increase `--led-slowdown-gpio`.

HummingBuddha, 2018-04-17:
Hey hzeller

Had some connection issue and the issue is solved now, but the flicker is high if I dont use PWM = 1 and eventually if I use I loose out colour renders... Is there any possible way to stop other than adafruit adapters as its out of my reach.  And LED's are rendering as RBG rather than RGB what would be the cause, I have checked the wiring its perfect.. Using sequence RBG to render as RGB.

HummingBuddha, 2018-04-19:
Hey hzeller

Had some connection issue and the issue is solved now, but the flicker is high if I dont use PWM = 1 and eventually if I use I loose out colour renders... Is there any possible way to stop other than adafruit adapters as its out of my reach. And LED's are rendering as RBG rather than RGB what would be the cause, I have checked the wiring its perfect.. Using sequence RBG to render as RGB. Do we have any option for setting x&y co-ordinates in RPI-RGB..

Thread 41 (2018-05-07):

ft-server and RPi3

pilif-pilif, 2018-05-07:
Hello Hzeller,
thank you for sharing this great project.

I am facing the following issue here -
when I compile the server with make FT_BACKEND=ft (then start it as root) and then use send-text or send-image (on localhost) I can't see that the GPIO pins toggle, when I measure with an oscilloscope. For example the clock pin. I still don't have (jet) the  spixels PCB, but from layout I don't think it is required for the RPI Pins to toggle? I think Rpi3 is supported too?

If I compile with FT_BACKEND=terminal I can see the send Image/Text im Terminal.

hzeller, 2018-06-21:
make sure to update the submodules. Recent raspians changed some memory sizes, and the detection logic needed to change, which is added in head of the respective repos, but I don't know if the dependencies in Flaschen-Taschen are already updated to use the latest.

Razzeee, 2018-06-21:
Thanks, we finished our screen last weekend and everything works as expected. So this ticket can probably be closed. And it indeed was the lower version of the submodule that caused problems in the start.

dwright213, 2018-06-21:
First off just have to say Henner you're a G for building all this stuff, from software to PCBs. In my time working on building this Flaschen Taschen I've been super impressed by how much work you must have put into this project. Okay, with that out of the way...

Git status tells me I am running the latest spixels commit, where it you made the changes to get it working on newer raspians. Might there have since been updates to the rgb-matrix submodule that spixels would also need?

I tested my solders on the spixels board and they all seem to check out, but I don't have an oscilloscope and don't normally work in C++, so I am a little lost on what to check next. I feel like there is some really obvious thing I am overlooking. I didn't solder all the components to the board, just the 22µF cap, a 100nF cap, a level shifter, and some header pins to connect it to the pi and my ws2801 string.

Sorry to hijack the thread, it was the closest I could find to the problems I am having. I can start a new thread, if need be.

dwright213, 2018-06-21:
Thanks for the response! I'm still plugging away at this, but there seems to be improvement. My partner on this project is trying to get VLC to compile on a rpi, but that's a whole nother can of worms.

Clock/data: I've changed those around a few times just to be sure, but they appear to be accurately labeled by the factory. I was able to run some of Adafruit's examples before I got the board completed, by connecting the string directly to the gpio ports.

Update: I connected the ground wire in the ws2801 string to the gpio ground pin and got slightly different results:
1: the first led in the string is no longer on, a few others are on though, near the middle of the string. Possibly from some kind of noise as I connected the wire to the pin.
2: They all immediately turn off when I run [spixels/examples/simple](https://github.com/hzeller/spixels/blob/900127ac396804c6d7fc9c8a01ed812f6f8dc7f3/examples/simple.cc). None turn on or blink though.
I have made minor changes to simple.cc, mostly replacing "CreateDirectMultiSPI" with "CreateDMAMultiSPI", and "CreateAPA102Strip" with "CreateWS2801Strip", to suit my led type.

The board: yeah, that's the board I am using. The Oshpark page for it cites May 8th, 2016 as the upload date for the design.

Connectors: my panel is connected to the one marked P1 on the board, which I am guessing would be SPI_P1 on main.cc.

As for wiring, I copied your design of crates of 5x5 bottles, except only now do I have the connectors' ground hooked up to raspi's gpio ground. Materials-wise I wanted to steal your crates and glass bottles concept, but for money and weight savings I opted for insulation foam and plywood grids holding plastic water bottles. My hope is that wiring is the same.

dwright213, 2018-06-21:
Okay, I connected the led string to P2 and in simple.cc changed strip1 to map to SPI_P2, compiled and ran it and it appears to be working now! I wonder if actually bungled a solder on this board. It's my first time soldering smt stuff. I'll recheck P1's connections specifically.

pilif-pilif, 2018-06-23:
it took me some time to report back but [ hzeller/spixels@900127a](https://github.com/hzeller/spixels/commit/900127ac396804c6d7fc9c8a01ed812f6f8dc7f3) was the solution to my problem.
Thanks @hzeller

Closed 2018-06-23.

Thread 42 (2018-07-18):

Only able to control led strings on SPI_P2 and SPI_P13.

dwright213, 2018-07-18:
I checked all my solders (I'm using the spixels board), and all the connectors have solid continuity from their pins to the 74HCT245's pins.

This has been a persistent problem though, across 2 spixels boards (the other board I put together just for testing, only used one 74HCT245, and only SPI_P2 was working). 2 different rpis (3b and  3b+), and quite a few Raspbian lite installations, so my only guess is that the cause is some difference in gpio/spi functionality between the rpi2 and rpi3.

I could be way off, I am not sure what else I should be testing though, at this point. Any ideas?

hzeller, 2018-07-18:
mmh, so you are a bit sparse with the information you provide.

- Which version of the Spixels board are you using ? (typically 2016-05-07 I guess). All should work, but I had speciality versions handed out as well, so knowing the reference is good.
- I suppose, clock also works ? Otherwise you would not see any LED strip update on P2/P13.
- Do you see the same problem with the DMA or direct-multi SPI ?
- Are you using FlaschenTaschen or the Spixel library directly ?
- What kind of LED strips are you using ? WS2801, APA102 or LDP6803
- If you have a newer Pi make sure to use the spixels version newer than May or so as there was a workaround needed (version >= https://github.com/hzeller/spixels/commit/900127ac396804c6d7fc9c8a01ed812f6f8dc7f3 )
- did you disable other things that might interfere with the GPIOs ? 1 wire connection, no pigpio etc. might mess with the system (generally it is a good idea to use a minimal raspbian lite version if you have not already).

dwright213, 2018-07-18:
Sorry about that, I'll fill you in.

- I am using the 05-07-2016 board.
- I'm not sure how to check if clock works (check dc voltage on the SCLK pin?) but I figured that the ports that are working would indicate that.
- I haven't tried using CreateDirectMultiSPI, only CreateDMAMultiSPI, due to the advice of  spixels/examples/simple.cc, where it says:
`    // If you are using WS2801, then you need CreateDMAMultiSPI() instead,
    // as these strips are finicky with timings.
`
- I am using FlaschenTaschen with the Spixels library.
- The LED strip type I am using is WS2801.
- Affirmative, I definitely made sure I am using the latest version of both Spixels and FlaschenTaschen.

And I will go ahead and check that nothing else is messing with the gpio..

dwright213, 2018-07-18:
Update:
I disabled i2c and "remote gpio" with the raspi-config utility, so I guess I did indeed have pigpio running.

I also installed wiringPi (which I probably need to uninstall now). Before turning off remote gpio (and with ft_server running) , wiringPi's readall command gave me the following, if it's helpful:

` `+-----+-----+---------+------+---+---Pi 3+--+---+------+---------+-----+-----+
 | BCM | wPi |   Name  | Mode | V | Physical | V | Mode | Name    | wPi | BCM |
 +-----+-----+---------+------+---+----++----+---+------+---------+-----+-----+
 |     |     |    3.3v |      |   |  1 || 2  |   |      | 5v      |     |     |
 |   2 |   8 |   SDA.1 | ALT0 | 1 |  3 || 4  |   |      | 5v      |     |     |
 |   3 |   9 |   SCL.1 | ALT0 | 1 |  5 || 6  |   |      | 0v      |     |     |
 |   4 |   7 | GPIO. 7 |   IN | 1 |  7 || 8  | 0 | IN   | TxD     | 15  | 14  |
 |     |     |      0v |      |   |  9 || 10 | 1 | IN   | RxD     | 16  | 15  |
 |  17 |   0 | GPIO. 0 |   IN | 0 | 11 || 12 | 0 | OUT  | GPIO. 1 | 1   | 18  |
 |  27 |   2 | GPIO. 2 |  OUT | 0 | 13 || 14 |   |      | 0v      |     |     |
 |  22 |   3 | GPIO. 3 |  OUT | 1 | 15 || 16 | 0 | OUT  | GPIO. 4 | 4   | 23  |
 |     |     |    3.3v |      |   | 17 || 18 | 0 | IN   | GPIO. 5 | 5   | 24  |
 |  10 |  12 |    MOSI | ALT0 | 0 | 19 || 20 |   |      | 0v      |     |     |
 |   9 |  13 |    MISO | ALT0 | 0 | 21 || 22 | 0 | IN   | GPIO. 6 | 6   | 25  |
 |  11 |  14 |    SCLK | ALT0 | 0 | 23 || 24 | 1 | OUT  | CE0     | 10  | 8   |
 |     |     |      0v |      |   | 25 || 26 | 1 | OUT  | CE1     | 11  | 7   |
 |   0 |  30 |   SDA.0 |   IN | 1 | 27 || 28 | 1 | IN   | SCL.0   | 31  | 1   |
 |   5 |  21 | GPIO.21 |  OUT | 1 | 29 || 30 |   |      | 0v      |     |     |
 |   6 |  22 | GPIO.22 |  OUT | 1 | 31 || 32 | 0 | OUT  | GPIO.26 | 26  | 12  |
 |  13 |  23 | GPIO.23 |   IN | 0 | 33 || 34 |   |      | 0v      |     |     |
 |  19 |  24 | GPIO.24 |  OUT | 1 | 35 || 36 | 0 | OUT  | GPIO.27 | 27  | 16  |
 |  26 |  25 | GPIO.25 |   IN | 0 | 37 || 38 | 0 | IN   | GPIO.28 | 28  | 20  |
 |     |     |      0v |      |   | 39 || 40 | 1 | OUT  | GPIO.29 | 29  | 21  |
 +-----+-----+---------+------+---+----++----+---+------+---------+-----+-----+
 | BCM | wPi |   Name  | Mode | V | Physical | V | Mode | Name    | wPi | BCM |
 +-----+-----+---------+------+---+---Pi `3+--+---+------+---------+-----+-----+``

dwright213, 2018-07-24:
Yes! Sorry for the lack of response, it's been crunch time on this project, so I've been putting lots of work in.

It may have been my installation, but I think it was actually my soldering and testing skills that were the problem, because after resoldering and testing each leg of the level shifters, I was able to get them working. Sorry to pester you with it, this project has been a comedy of errors for me.

Unrelated, but I have an Ansible project for Flaschen Taschen, to standardize pi setup and simplify code pushing. Maybe someone else browsing the issues could use it.

https://github.com/dwright213/ft-deploy

Closed 2018-07-23.

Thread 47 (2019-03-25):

One client, multiple server

hakao32, 2019-03-25:
Hello,
I realy like what you did with tlaschen-taschen. I wonder that is it possible to broadcast to multiple server? Let say i have 4 LED matrix driving by RPi for each. I want to play a video on them like:
 |XY|
 |ZT|
->
|X|  |Y|
|Z| |T|
so, is it possible that divide the video or image to 4 and broadcast them to 4 server?

meikel-k, 2020-11-14:
If you are using VLC player as the source , just type in the the adapter falschen the IP adress of your network  with last three didgits ."255". This is the network broadcast IP. All PI's will take the signal receivingon that IP . For sample , 192.168.178.255

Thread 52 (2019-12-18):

clients on other OS ?

guyverckw, 2019-12-18:
Hi,
  I just tried sending images and videos from my Raspberry Pi to the LED panel.  I wonder if there is other clients that run on other OS platform that I can make use of?  Like Windows, even iOS or Android?
  Thanks in advance.

hzeller, 2019-12-18:
It is just uses UDP packets, which is the simplest network interface that is supported by all operating systems. I have seen people writing clients in Java or Python (Python library is included with this repository) or even JavaScript.

The C++ code uses a sufficiently small subset of operating system functionality that it should be possible to compile on any OS as well.

guyverckw, 2019-12-18:
Can you point me to the link of Python implementation?  Thanks a lot.

hzeller, 2019-12-19:
Python API is here: https://github.com/hzeller/flaschen-taschen/tree/master/api/python

guyverckw, 2019-12-19:
Thanks a lot!

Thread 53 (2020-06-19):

Server error: Message too long in vout display flaschen

kirkas, 2020-06-19:
Hi,

First of all, thank you so much for your work on flashen-tashen & rpi-rgb-led-matrix ! I've been experimenting with RPI and LED matrix for a couple months and all your work has saved me months (years!) of work :)

Second, I'm having some issues streaming to the RPI server from another computer.

**Context**: trying to send my square, 64x64 pixel video (`squarevideo.h264`) to the ft-server, built to output on a 64x64 LED matrix display.

I've managed to make it work when streaming the video from the RPI itself (i.e. run through an SSH console):

```
./send-video -g 64x64 home/pi/Library/picamerascript/squarevideo.h264
```

Now if I run the same command, but from my computer, I get this

```
./send-video -h raspberrypi.local -g 64x64 ~/rasberrypi/squarevideo.h264
flaschen vout display error: sendmsg: error Message too long in vout display flaschen
flaschen vout display error: sendmsg: error Message too long in vout display flaschen
flaschen vout display error: sendmsg: error Message too long in vout display flaschen
...
```

Interestingly, if I reduce the dimension to anything _below_ 56 it _does_ work
```
./send-video -h raspberrypi.local -g 32x32 ~/rasberrypi/squarevideo.h264
./send-video -h raspberrypi.local -g 55x55 ~/rasberrypi/squarevideo.h264
```
^ these works, but `-g 56x56` will fail.

------
Setup
OSX: Software: Max OSX catalina 10.15.4 (19E287))
OSX: Terminal: ITerm3
Pi: Hardware: Raspberry Pi 4 Model B Rev 1.1
Pi: Software: Raspbian GNU/Linux 10 (buster)

Craft4Cube, 2020-06-26:
I had the same issue. It seems MacOS limits UDP packages to 9216 bytes. You can use `sudo sysctl -w net.inet.udp.maxdgram=65535` to change this limit.

kirkas, 2020-06-26:
oh dang - That worked :) Thank you so much!

derwentx, 2020-09-09:
it would be great if this were in the documentation somewhere!

hzeller, 2020-09-09:
I've made the used UDP size configurable now and added a documentation about the OSX issue in https://github.com/hzeller/flaschen-taschen/tree/master/client#udp-size

Closed 2020-06-26.

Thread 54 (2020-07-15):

Streaming video through Flaschen Taschen to rgb led matrix

DennisMamedov, 2020-07-15:
Hey!

I'm trying to setup flaschen taschen but I can't seem to stream the vlc to the udp server. I'm running:
`vlc --vout flaschen --flaschen-display=localhost --flaschen-width=64 --flaschen-height=64 "https://www.youtube.com/watch?v=QH2-TGUlwu4" --no-audio`
I'm getting:
>VLC media player 3.0.10 Vetinari (revision 3.0.10-0-g7f145afa84)
[01e52db0] vlcpulse audio output error: PulseAudio server connection failure: Connection refused
[01e775c0] main interface error: no suitable interface module
[01dd7b58] main libvlc error: interface "globalhotkeys,none" initialization failed
[01dd7b58] main libvlc: Running vlc with the default interface. Use 'cvlc' to use vlc without interface.
[01e775c0] skins2 interface error: cannot initialize OSFactory
[01e775c0] [cli] lua interface: Listening on host "*console".
VLC media player 3.0.10 Vetinari
Command Line Interface initialized. Type 'help' for help.
 [b0f00d58] http stream error: local stream 1 error: Cancellation (0x8)
[b042ca40] mmal_codec decoder: VCSM init succeeded: CMA
[b0d192f8] chain filter error: Too high level of recursion (3)
[b0d18dd0] main filter error: Failed to create video converter
[b0d192f8] chain filter error: Too high level of recursion (3)
[b0d18dd0] main filter error: Failed to create video converter
[b0d192f8] chain filter error: Too high level of recursion (3)
[b0d18dd0] main filter error: Failed to create video converter
[b0d192f8] chain filter error: Too high level of recursion (3)
[b0d18dd0] main filter error: Failed to create video converter
[b0d192f8] chain filter error: Too high level of recursion (3)
[b0d18dd0] main filter error: Failed to create video converter
mmal: mmal_vc_port_info_set: failed to set port info (3:0): EINVAL
mmal: mmal_vc_port_set_format: mmal_vc_port_info_set failed 0xb0d05380 (EINVAL)
[b0d03340] mmal_codec filter error: Failed to commit format for output port vc.ril.hvs:out:0(OPQV) (status=3 EINVAL)
Segmentation fault`

Initialising the server with:
`~/flaschen-taschen/server $ sudo ./ft-server --led-slowdown-gpio=4 --led-cols=64 --led-parallel=2`

any idea?

DennisMamedov, 2020-07-15:
Have to say that simply running `vlc "any youtube link"` works, only when i use flaschen it gives me that error.

nmstoker, 2021-11-07:
Hi @DennisMamedov - not sure if you figured things out. It seems most likely to be down to UDP limits.  See the answer here for details relating to VLC / UDP size limits.

As a temporary work-around / test, if you try using a smaller values for width and height, you should see an image come through (assuming everything else is working)

`vlc --vout flaschen --flaschen-display=ledframe --flaschen-width=40 --flaschen-height=32 "https://www.youtube.com/watch?v=XXXXXXXXX" --no-audio`

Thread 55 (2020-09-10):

Problem with --led-chain

grthor, 2020-09-10:
Hi,
my goal is to stream videos via VLC to an LED matrix, but I have encountered a problem that I can't get fixed.

If I run
```
root@raspberrypi:~/home/pi/flaschen-taschen/server $ ./ft-server --led-rows=32 --led-cols=64
--led-chain=8 --led-parallel=2 --led-pixel-mapper "U-mapper"
```
the led matrix stays black. If I run [changed `--led-chain=8` to `--led-chain=4`]
```
root@raspberrypi:~/home/pi/flaschen-taschen/server $ ./ft-server --led-rows=32 --led-cols=64
--led-chain=4 --led-parallel=2 --led-pixel-mapper "U-mapper"
```
the led panels light up and show the video. I changed `--led-chain=4` to `--led-chain=6` and the led-panels turn black again.
Depending on the led chain length something is displayed or not.

Here are some facts about my setup
- I use 16 32x64 pixel LED modules with the following mapping:
```
   [<][<][<][<]  }--- Pi connector #1
   [>][>][>][>]
   [<][<][<][<]  }--- Pi connector #2
   [>][>][>][>]
```
- For wiring I use an Active-3 breakout board.
- The setup works. I can run examples from rpi-rgb-led-matrix/examples-api-use. All panels show the correct content.
- I use an RPi 4 with Raspbian lite.

I hope this helps solving the problem. If you need any further information i try to answer asap.

Best regards
Thorben

meikel-k, 2020-11-14:
I have the same problem, same setup and starting the server

The server starts with resolution 256x128
If I setup VLC -Video Flaschen , with width 256 and height 128 the Display keeps black,
Trying to setup VLC Flaschen with width 256 and height 64 it works but only shows on channel 1 the first two display rows.
Other apps like video-viewer or image viewer uses the whole display.

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

How can I get VLC stream with height above 64 pixel

hzeller, 2021-07-26:
This sounds similar to #61 - essentially the default VLC has a limit in size of the image, but in the issue mentioned there is a link to a modified fork of VLC which allows larger images.

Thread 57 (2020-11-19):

Streaming with VLC on large LED-Matrix

meikel-k, 2020-11-19:
Hello ,
first,  thank you for the great work you have done with this fantastic apps.
I am running a project for our club to build several different LED-Matrix displays and most of all went fine and works.

Description and successful test of the size but slow:

I do have one display with 4cols and 5rows of 64x32 led-displays.
- FT-Server runs with 256x160 on port 1337
- UDP buffer on the Pi's is increased to max.
- Using the flaschen-taschen client –> send-image, works fine.
- Using the flaschen-taschen client -> send-video works as well on the whole display size
   Command:   ./send-video -g256x160+0+0 -h <host> <video> , which is fine but very slow
- Using two Pi’s one for the matrix with the ft-server and the other to decode the video and send it over the network,
   works better but still slow.
- Sending a webcam-stream with  command :  ./send-video -g256x160+0+0  http://<camera>  ,
   works fine .

Now the issue:
I know that you did not wrote the vlc-client flaschen, perhaps you have an idea where to change to get it work.

Using the VLC on a PC or running on a PI , the max size setup in the VLC Flaschen adapter which will work is width = 192 , height = 112.
All other larger setup sizes result in black display no stream visible.

Wondering how Dirk in Schabeutz got his very large display working with stream showing.
Hope you have an idea or can help with this.

Kind regard

hzeller, 2020-11-19:
I sent a patch a while back to vlc-devel that allows vlc to chunk the image to allow for large screens https://mailman.videolan.org/pipermail/vlc-devel/2020-March/132387.html

I was then getting busy to work on some technical stuff fighting some pandemic, so never got around to address the review comments. But it should be possible for you to just take this patch and make your copy of VLC work with it.

meikel-k, 2020-11-19:
Hello Henner,
wow , thanks so much for the fast respond.

I have just downloaded the source code of VLC and made the patches in the flaschen.c.
Now fighting with my system to get the VLC with the changed file compiled and installed.

I will let you know after my success !

best regards
Michael

meikel-k, 2020-11-19:
I belive this would be the same answer for the issue:  **Problem with --led-chain**  , raised by grthor on the 10Sept.

meikel-k, 2020-11-30:
Hello Henner,

thanks again for you help.
It was really very hard staff to get a running system on Linux Mint ,  to be able to complie the VLC - player package.
Only missing packages , errors ...

At least I got one version running which gives me a compilation via Docker for a Windows System.
https://medium.com/@tobias.strg/compiling-vlc-3-x-in-2020-a390c6a73c24

I got now the latest Version of VLC 3.011.1

Made the patch you have send and compiled the VLC-package -> and now I am lucky to run a display with dimension (width x height) 256x160 pixels -  driven by VLC -Player

Very great stuff.

Thanks  a lot for your development .

I wil start now again to get a Linux running to be able to compile a Linux Version.
It will be better run on my slow laptop .

Best regards

Michael

meikel-k, 2020-12-19:
Thanks again all works fine , now tryining to send to two different IP's , will see how I can get this work. The interface is already done

win95c, 2022-03-23:
Hallo,
is there a possibility to expand the display to 256x196 pixels?
Best regards
Frank

meikel-k, 2022-03-23:
Hello Frank

with the patch supplied by Henner , VLC can now send larger images, as
it split the image in several UDP pages each max filled.
So you can also run 256x192 pixel.

I was getting 256 x 160 , because the monitors I have build should be
close to 16:9 resolution.
So I was using 4x Matrixmodules 64x32 in a line by 5 Matrixmodules in
vertical ( 20 Displaymodules)
using Raspberry PI3 - B with a Shield for RGB-LED Matrix.

Kind regards
Michael

Am 23.03.2022 um 14:36 schrieb win95c:
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

win95c, 2022-03-24:
Hi Michael,
Thank you for your prompt reply. I used the patch provided by Henner with VLC4.0. My display can do 256x192. There is always a black border of about 30 lines below. At first I suspected a hardware defect. I also swapped out the Raspberry+ Matrix. The error remains.
For me, this is the sign that the patch only works up to 256x160 pixels.
It doesn't work at all without a patch.
I am using Raspberry PI3 - B. The frame rate >55 Hz. 4 cols(64) x 3rows(64) pixel matrix.
The perspective should be 5 cols(64) x 3rows(64).

Maybe there are more users like where I can exchange ideas in German.

Best regards
Frank

win95c, 2022-04-21:
Hello Henner,
you can look again over the patch of VLC Flaschen-taschen. The patch only works up to a maximum of 256x160 pixels. In addition, a black border of about 30 lines remains at 256x192.
In terms of hardware, I rule out a problem, because images or text work via led-image-viewer. The problem is still with the VLC. I used a self-made version of VLC4dev. I can't get any further at this point.
Best regards
Frank

Closed 2020-12-19.

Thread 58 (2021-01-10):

Just wanted to say thank you

mmartinortiz, 2021-01-10:
Some weeks ago I bought a RGB Led Matrix, and during this last holidays I spent some days programming a video game for the matrix. Without your work, this could not be possible.

Thank you very much for enabling others :-)

PD: In case anyone is interested in putting to use their RGB Matrix: https://github.com/mmartinortiz/rgb-led-matrix-space-invaders

hzeller, 2021-01-10:
Thanks for the feedback :)
Enjoy your new LED game goodness!

Closed 2021-01-14.

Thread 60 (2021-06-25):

Aspect ratio and/or aliasing?

Kevin-Prichard, 2021-06-25:
Howdy @hzeller!  I hate to use an issue to pose newb questions, but where else are things flaschen-taschen discussed?

Looking thru the code to find whether specifying an aspect ratio is possible, and haven't found that yet.

Similarly, when pixels in source image data are mapped to LEDs, are they aliased?

If either or neither -- would these be (a) desirable feature(s) for the flaschen-taschen community? Would it be worth my time to add these? I mean, it would be for me, because the device I am building will result in uniformly rectangular pixel cells, and essentially have no control over that (and suspect that aspect ratio is a thing others might want)

I see that [libswscale](https://github.com/FFmpeg/FFmpeg/tree/master/libswscale) is employed, and yes it can scale images to match the wxh of an output device's aspect ratio. However, consider a device where physical lay is equivalent, widthPhys=heightPhys but pixel density is different, e.g. widthPixel=2*heightPixel.

Are such nonsquare pixel layouts accommodated by libswscale -and, if so, do I need to do anything else? Ty

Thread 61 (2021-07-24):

VLC --vout flaschen issues on a working setup

gregtap, 2021-07-24:
Hello fellow pixel lovers,

First, let me emphasis that this flaschen tashchen ppm over UDP protocol is golden. Thank you so much for that.

We have on a pi4 the server running :

```~/flaschen-taschen/server$ sudo ./ft-server --led-rows=32 --led-cols=64 --led-chain=6 --led-parallel=2 --led-no-hardware-pulse --led-slowdown-gpio=5 --led-show-refresh```

Then on an other machine on the network :

```./send-video  -h 100.119.152.99 -g 384x64 ~/Downloads/bandeau\ greg.mp4```

video is [available here(https://storage.googleapis.com/silvr_temp/bandeau%20greg.mp4)

It all works very smoothly at 95hz. Increasing the screen may be a challenge if the fps drops too much, we will see about that.

Now, what I would like to do is to be able to stream a video. The master plan would be to eventually build something that can capture a web HTML 5 canvas as a video stream and push it to flaschen taschen. This will make coding animations accessible to web developers.

To validate the streaming performance I tried VLC.

Ubuntu  5.4.0-80-generic #90-Ubuntu
```VLC media player 3.0.9.2 Vetinari (revision 3.0.9.2-0-gd4c1aefe4d)```

Desktop computer with a Nvidia grahic card / Ryzen.

``` vlc --vout flaschen --flaschen-display=100.119.152.99 --flaschen-width=64 --flaschen-height=384 /home/greg/Downloads/bandeau\ greg.mp4
VLC media player 3.0.9.2 Vetinari (revision 3.0.9.2-0-gd4c1aefe4d)
[000055efdd8945b0] main libvlc: Running vlc with the default interface. Use 'cvlc' to use vlc without interface.
[00007f48d8002400] main filter error: Failed to create video converter
[00007f48d8002400] main filter error: Failed to create video converter
[00007f48f0c175a0] avcodec decoder: Using NVIDIA VDPAU Driver Shared Library  450.80.02  Wed Sep 23 00:46:46 UTC 2020 for hardware decoding
[00007f48d8023390] blend blend error: no matching alpha blending routine (chroma: YUVA -> VDV0)
[00007f48d8023390] main blend error: blending YUVA to VDV0 failed
[00007f48d80013b0] flaschen vout display error: sendmsg: error Message too long in vout display flaschen
[00007f48d8023390] blend blend error: no matching alpha blending routine (chroma: YUVA -> VDV0)
[00007f48d8023390] main blend error: blending YUVA to VDV0 failed
[00007f48d80013b0] flaschen vout display error: sendmsg: error Message too long in vout display flaschen
[00007f48d8023390] blend blend error: no matching alpha blending routine (chroma: YUVA -> VDV0)

[... many more...]

 [00007f48d80013b0] flaschen vout display error: sendmsg: error Message too long in vout display flaschen
[00007f48d80013b0] flaschen vout display error: sendmsg: error Message too long in vout display flaschen

[... many more...]

```

With -vvv

```
[h264 @ 0x7fab00cf2080] nal_unit_type: 9(AUD), nal_ref_idc: 0
[h264 @ 0x7fab00cf2080] nal_unit_type: 1(Coded slice of a non-IDR picture), nal_ref_idc: 3
^C[00005652de4c55b0] main libvlc debug: exiting
[00005652de4c55b0] main libvlc debug: removing all interfaces
[00005652de5a7d20] main interface debug: removing module "qt"
[00005652de563640] main playlist debug: deactivating the playlist
[00005652de563640] main playlist debug: incoming request - stopping current input
[00007faae80013b0] flaschen vout display error: sendmsg: error Message too long in vout display flaschen
[00007faae8023530] main blend debug: looking for video blending module matching "any": 1 candidates
[00007faae8023530] blend blend error: no matching alpha blending to
```
I tried smaller resolution 10x10, in case it was a UDP packet limitation but atlas.

Any ideas on how to approach this issue?

hzeller, 2021-07-25:
384 x 64 pixels with 3 bytes each (RGB) is around 72 kIB, which is larger than the 64kIB that fits in a UDP packet.

The `send-video` and other tools in this library make sure to break up the packet into smaller ones, so you can send arbitrary size images.

The VLC tries to put everything in one packet, but then fails (which you see in the `sendmsg: error Message too long` message).

I did make a patch to VLC to fix that ( https://mailman.videolan.org/pipermail/vlc-devel/2020-March/132387.html ),
that was last year in March; however, there were review comments, but I never got around addressing them as I was getting involved with pandemic related technical things that required my attention - that is why it is not in VLC yet.

Anyway, you can try my fork of vlc in the branch `flaschentaschen-large-image`
https://github.com/hzeller/vlc/tree/flaschentaschen-large-image
That contains the [necessary change](https://github.com/hzeller/vlc/commit/a99830eb517a55e6f0148e59e305e965a57f6019) to make VLC work with arbitrary large images. I just refreshed that to be based on latest VLC.

For your applicataion: I'd probably would not go the route through a video encoding and back, but directly encode the raw bytes of the HTML5 canvas as ppm packets (very easy to encode). In the patch you see how the large canvas is split into multiple stripes that each are less than 64kiB.

gregtap, 2021-07-26:
Now it all makes sense! An other quality answer, thank you so much.

I don't think we can send UDP from browser javascript just yet however HTML5 canvas have a [captureStream](https://developer.mozilla.org/en-US/docs/Web/API/HTMLCanvasElement/captureStream)().

https://webrtc.github.io/samples/src/content/capture/canvas-pc/

We are going to look into that.

Closed 2021-07-26.

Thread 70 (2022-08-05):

Sending to outputs

Pont3x, 2022-08-05:
I want to stream an image from my pi to itself (via localhost). I also want to see in the ssh terminal the same output my pi should be showing on the rpi-rgb-matrix (because in my configuration you cant see the matrix from the point of the controller).
(How) Would it be possible to output via matrix and terminal?

In case this doesn't work, how could I send from a client to the client itself functioning as server and the pi as an seperat server? (so you would have two servers with one output instead two outputs at one server)

Sincerely
Christian

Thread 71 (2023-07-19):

Four quadrants of a 128x64 to be four 64x32 virtual boards

smith288, 2023-07-19:
So I am running ft-server on a raspbery pi with a 128x64 board (and Arduino hat).

I discovered I can send an image to x & y coordinates so had the great idea to run 4 different pixlets and then take each resulting output gif to an assigned quadrant of the board using the send-image command.

./send-image -g 64x32+0+0 -h matrixboard.local ./tmp/matrixboard_pixletexample1_pixlet.gif -c
./send-image -g 64x32+0+32 -h matrixboard.local ./tmp/matrixboard_pixletexample2_pixlet.gif -c
./send-image -g 64x32+64+0 -h matrixboard.local ./tmp/matrixboard_pixletexample3_pixlet.gif -c
./send-image -g 64x32+64+32 -h matrixboard.local ./tmp/matrixboard_pixletexample4_pixlet.gif -c

It all works great to be honest but my biggest issue seems to be if the gif is animated in any way, the ft-server has a really tough time animating it.  I thought maybe it was the fact I was sending several animated gifs to it but I disabled them all and just sent one that was a 3 frame gif and it wouldnt animate it at all.

Here's an example of an animated gif that is just three frames

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

Is there any magic the ft-server has that can provide better support for animated gifs?

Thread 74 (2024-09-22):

VLC: possibility to reduce color depth?

beta-tester, 2024-09-22:
hi, i am very new to VLC for Flaschen-Taschen.
i am using VLC 3.0.21 that is shipped with Raspberry Pi OS (bookworm) 64bit.
i have the ft-server running for a 256x128 LED-Matrix (two chains with 4x 64x64 outdoor panels).
so on the server i am running the ft-server with:
```
sudo ~/git/flaschen-taschen/server/ft-server --led-rows=64 --led-cols=64 --led-chain=4 --led-parallel=2 --led-multiplexing=1 --led-pwm-bits=5 --led-pixel-mapper=Rotate:180 --led-show-refresh
```

on the other raspberry pi with Raspberry Pi OS (bookworm) 64bit, i tried to run:
```
vlc --vout=flaschen --flaschen-display=matrix.local --flaschen-width=256 --flaschen-height=128 video.mp4
...
[0000007f440013f0] flaschen vout display error: sendmsg: error Message too long in vout display flaschen
[0000007f440013f0] flaschen vout display error: sendmsg: error Message too long in vout display flaschen
...
```

i know, a single UDP frame can only hold up to 65536 bytes and my display size with 98304 bytes does not fit to a single UDP frame. that's why i get the error messages `error Message too long in vout display flaschen`.

i am wondering if there is a possibility to reduce the color depth vlc is sending to the ft-server.
e.g. if i can set the color depth down to 5bit per color => rrrrrgggggbbbbb => 2 byte per pixel, then a image of 256x128x2byte has 65536 bytes, what would fit to a single UDP frame.

hzeller, 2024-09-23:
Color depth reduction is not possible, but it is possible to send in multiple packets.

I once actually had a fix for that to patch into VLC https://mailman.videolan.org/pipermail/vlc-devel/2020-March/132387.html
... but that was at the beginning of the pandemic and then I was getting busy making PPE and did not finish that patch.

hzeller, 2024-09-23:
(If you are just interested in the video, no sound, then https://github.com/hzeller/flaschen-taschen/tree/master/client#send-video might be sufficient)

beta-tester, 2024-09-23:
so the patch for multiple packages is not implemented in the stock vlc 3.0.21 of the Raspberry pi repository?
is it maybe in the windows version?

i am not interest in sound.
does 'send-video' also downscale videos to the required size of the display and can it open youtube videos?

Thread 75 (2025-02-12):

VLC 4 streaming broken: Colors are off

LostInCompilation, 2025-02-12:
When using the latest VLC compiled from source code (master branch) to stream my desktop to **ft-server** the colors are very off. The image always looks very blueish (see image, VLC is capturing my desktop and sending it to ft-server). The position of the pixels seems to be correct (you can make out the macOS dock at the bottom).
VLC 3.x.x works, however I cant get VLC 3.x.x to compile on ARM Mac, only VLC 4 works (and I wanted to implement the large display mod with multiple UDP packets as its not in the current VLC source).

I tried a few things in flaschen.c inside VLC to fix the issue (I assumed the color data is YUV and converted it, changed RGB order, 16-235 -> 0-255, ...) but I cant get it to work. The image is always wrong.
I reverted all changes, compiled VLC from a fresh clone and took the screenshot posted here.

@hzeller Do you have any suggestion for me what could have changed in VLC 4 for this to break? I'm.a bit out of ideas what to try and why the colors look so off only with VLC 4.

This is the flaschen.c inside VLC master branch: https://code.videolan.org/videolan/vlc/-/blob/master/modules/video_output/flaschen.c?ref_type=heads

## Image
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

LostInCompilation, 2025-02-12:
A quick color test. **Left** is the correct color, **right** is the color that ft-server displays when VLC4 is streaming to it.

# Red
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

# Green
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

# Blue
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

# Black
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

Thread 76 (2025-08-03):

Data loss during video play over network (Wifi vs Ethernet)

tempelmann, 2025-08-03:
Just for the record, I'll note this here until I have time to investigate further:

I am using a rpi-matrix with 256x384 px, driven by a Raspi 4. Another Raspi sends a video to the full size to it, over Wifi. That works flawlessly.

But when I use an Ethernet connection instead of Wifi, then the received video is usually missing the lower third (it doesn't get updated or cleared) - but sometimes a full frame is displayed, and then the lower third keeps showing that one frame's content until another full frames comes thru.

It's not clear yet to me whether the server receives not all data or whether it receives all data but then fails to send it all to the matrix display.

But I wonder if the different MTU of the used networks is causing this (I believe that Wifi limits it a bit more than Ethernet). I've tried modifying the MTU via the nmtui tool, but it makes no difference, and `ifconfig` keeps showing that the MTU is 1500 for both interfaces anyway. I don't understand what's going on there.

Here's an example of how it looks when it's missing the lower part whereas the upper part gets updated properly playing the video:

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

hzeller, 2025-08-03:
256 * 384 * 3 bytes  = 294912. Each UDP packet can only carray 64k, so your image needs to be striped into 5 pieces. Now on top of that, the MTU of interfaces on typically not more than 1500 bytes, so the 64k packet will be split by the network interface into many more network frames. Maybe it has issues re-assembling them.

Maybe try to send smaller stripes. The `UDPFlaschenTaschen` constructor takes a fourth parameter, which is the max UDP size to send; currently the default is set to [the maximal practical size](https://github.com/hzeller/flaschen-taschen/blob/master/api/include/udp-flaschen-taschen.h#L44) but maybe setting that way smaller in your case to have that frame buffer split into many UDPs instead of just a few might help.

Just add a fourth parameter to [the constructor in the video-viewer](https://github.com/hzeller/flaschen-taschen/blob/master/client/send-video.cc#L178) with your value closer to your MTU.

tempelmann, 2025-08-03:
Thank you for responding so quickly. That brings up another question: Does it really transfer 3 bytes per pixel? Wouldn't a rgb565 (int16) value be sufficient? It certainly would for the LED panel as it doesn't do 8 bit per channel.
I'll look into your proposed workaround now.

tempelmann, 2025-08-03:
I have trouble understanding what `udp_server_run_blocking` on the server end is doing. Basically it does this:

```
loop
  read UDP packet from socket into single buffer
  extract img data from single buffer
  display->Send()
end

So, it always only does one socket read per display->Send. Which means that if the socket read isn't getting all data, it'll miss data for displaying.

My suspicion: While Wifi re-assembles the multiple UDP packets when doing the one socket read, ethernet doesn't do this.

The bug is therefore on the server's end: It fails to collect all UDP packets when they're fragmented.

tempelmann, 2025-08-03:
Sigh. I was able to improve the FPS by calling `display->Send()` from server's UDP reader only once a full frame has been received (or rather: once a new one starts, which I detect by checking for `img_info.offset_y == 0` (which is probably not working if a smaller window is transmitted, though, but good enough for me right now).

What I couldn't fix on the server's end is the loss of UDP packets, though. By adding some logging I found that the server does indeed not get to read all UDP packets that should be there, when using eth0. So I wonder if there's an issue on the sending end after all. Maybe the Pi 5's ethernet driver uses fewer buffers than the Wifi driver, and when trying to send 5 UDP packets in a row, it'll drop the last ones. I suspect one needs to add code to wait for the packets to be send before writing more into the pipe. I believe I ran into a similar issue with some UDP code I wrote for a Raspberry Pico last year. Will work on that tomorrow.

hzeller, 2025-08-04:
In https://github.com/hzeller/flaschen-taschen/commit/c7c2337eb9abe887410d3b6ecabff03970a6f524 I've now the server set the socket option to hold a few full frames, so that you don't have to set the `net.core.rmem_default` anymore.

It will complain if the `net.core.rmem_max` is not big enough and will suggest to set the value then (which then should be put in the in `/etc/sysctl.d/network-buffers.conf``), but no need to set the `rmem_default` there anymore.

Closed 2025-08-04.

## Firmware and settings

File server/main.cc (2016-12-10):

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
// Flaschen Taschen Server

#include <arpa/inet.h>
#include <errno.h>
#include <getopt.h>
#include <grp.h>
#include <pwd.h>
#include <stdio.h>
#include <stdlib.h>
#include <string.h>
#include <sys/ioctl.h>
#include <sys/socket.h>
#include <sys/types.h>
#include <unistd.h>

#include <string>

#include "composite-flaschen-taschen.h"
#include "ft-thread.h"
#include "led-flaschen-taschen.h"
#include "servers.h"

#if FT_BACKEND == 0
#  include "multi-spi.h"
#  include "led-strip.h"
#endif

#if FT_BACKEND == 1
#  include "led-matrix.h"
#endif

#define DROP_PRIV_USER "daemon"
#define DROP_PRIV_GROUP "daemon"

#ifndef __APPLE__   // Apple does not have setresuid() etc.
bool drop_privs(const char *priv_user, const char *priv_group) {
    uid_t ruid, euid, suid;
    if (getresuid(&ruid, &euid, &suid) >= 0) {
        if (euid != 0)   // not root anyway. No priv dropping.
            return true;
    }

    struct group *g = getgrnam(priv_group);
    if (g == NULL) {
        perror("group lookup.");
        return false;
    }
    if (setresgid(g->gr_gid, g->gr_gid, g->gr_gid) != 0) {
        perror("setresgid()");
        return false;
    }
    struct passwd *p = getpwnam(priv_user);
    if (p == NULL) {
        perror("user lookup.");
        return false;
    }
    if (setresuid(p->pw_uid, p->pw_uid, p->pw_uid) != 0) {
        perror("setresuid()");
        return false;
    }
    return true;
}
#endif

static int usage(const char *progname) {
    fprintf(stderr, "usage: %s [options]\n", progname);
    fprintf(stderr, "Options:\n"
            "\t-D <width>x<height> : Output dimension. Default 45x35\n"
#if FT_BACKEND == 2
            "\t--hd-terminal       : Make terminal with higher resolution.\n"
#else
            "\t-d                  : Become daemon\n"
#endif
            "\t--layer-timeout <sec>: Layer timeout: clearing after non-activity (Default: 15)\n"
            );
#if FT_BACKEND == 1
    rgb_matrix::PrintMatrixFlags(stderr);
#endif
    return 1;
}

int main(int argc, char *argv[]) {
    int width = 45;
    int height = 35;
    int layer_timeout = 15;
#if FT_BACKEND != 2
    bool as_daemon = false;
#endif
#if FT_BACKEND == 2
    bool hd_terminal = false;
#endif

#if FT_BACKEND == 1
    width = -1;    // Use size from matrix unless explicitly chosen.
    height = -1;
    rgb_matrix::RGBMatrix::Options matrix_options;
    rgb_matrix::RuntimeOptions runtime_opt;
    runtime_opt.daemon = -1;   // We deal with this manually belo
    runtime_opt.drop_privileges = -1;

    // First things first: extract the command line flags that contain
    // relevant matrix options.
    if (!rgb_matrix::ParseOptionsFromFlags(&argc, &argv,
                                           &matrix_options, &runtime_opt)) {
        return usage(argv[0]);
    }
#endif

    enum LongOptionsOnly {
        OPT_LAYER_TIMEOUT = 1002,
        OPT_HD_TERMINAL = 1003,
    };

    static struct option long_options[] = {
        { "dimension",          required_argument, NULL, 'D'},
#if FT_BACKEND != 2
        { "daemon",             no_argument,       NULL, 'd'},
#endif
        { "layer-timeout",      required_argument, NULL,  OPT_LAYER_TIMEOUT },
#if FT_BACKEND == 2
        { "hd-terminal",        no_argument,       NULL,  OPT_HD_TERMINAL },
#endif
        { 0,                    0,                 0,    0  },
    };

    int opt;
    while ((opt = getopt_long(argc, argv, "I:D:d", long_options, NULL)) != -1) {
        switch (opt) {
        case 'D':
            if (sscanf(optarg, "%dx%d", &width, &height) != 2) {
                fprintf(stderr, "Invalid size spec '%s'\n", optarg);
                return usage(argv[0]);
            }
            break;
#if FT_BACKEND != 2
        case 'd':
            as_daemon = true;
            break;
#endif
        case OPT_LAYER_TIMEOUT:
            layer_timeout = atoi(optarg);
            break;
#if FT_BACKEND == 2
        case OPT_HD_TERMINAL:
            hd_terminal = true;
            break;
#endif
        default:
            return usage(argv[0]);
        }
    }

    if (layer_timeout < 1) {
        layer_timeout = 1;
    }

#if FT_BACKEND == 0
    using spixels::MultiSPI;
    using spixels::CreateWS2801Strip;
    static const int kLedsPerCol = 7 * 25;
    MultiSPI *const spi = spixels::CreateDMAMultiSPI();
    ColumnAssembly *display = new ColumnAssembly(spi);

#define MAKE_COLUMN(port) new CrateColumnFlaschenTaschen(CreateWS2801Strip(spi, port, kLedsPerCol))

    // Looking from the back of the display: leftmost column first.
    display->AddColumn(MAKE_COLUMN(MultiSPI::SPI_P8));
    display->AddColumn(MAKE_COLUMN(MultiSPI::SPI_P7));
    display->AddColumn(MAKE_COLUMN(MultiSPI::SPI_P6));
    display->AddColumn(MAKE_COLUMN(MultiSPI::SPI_P5));

    // Center column. Connected to front part
    display->AddColumn(MAKE_COLUMN(MultiSPI::SPI_P13));

    // Rest: continue on the back part
    display->AddColumn(MAKE_COLUMN(MultiSPI::SPI_P4));
    display->AddColumn(MAKE_COLUMN(MultiSPI::SPI_P3));
    display->AddColumn(MAKE_COLUMN(MultiSPI::SPI_P2));
    display->AddColumn(MAKE_COLUMN(MultiSPI::SPI_P1));
#undef MAKE_COLUMN
#elif FT_BACKEND == 1
    ServerFlaschenTaschen *display
        = new RGBMatrixFlaschenTaschen(
            CreateMatrixFromOptions(matrix_options, runtime_opt),
            width, height);
#elif FT_BACKEND == 2
    ServerFlaschenTaschen *display =
        hd_terminal
        ? new HDTerminalFlaschenTaschen(STDOUT_FILENO, width, height)
        : new TerminalFlaschenTaschen(STDOUT_FILENO, width, height);
#endif

    // Start all the services and report problems (such as sockets already
    // bound to) before we become a daemon
    if (!udp_server_init(1337)) {
        return 1;
    }

#if FT_BACKEND != 2  // terminal thing can not run in background.
    // Commandline parsed, immediate errors reported. Time to become daemon.
    if (as_daemon && daemon(0, 0) != 0) {  // Become daemon.
        perror("Failed to become daemon");
    }
#endif

    // Only after we have become a daemon, we can do all the things that
    // require starting threads. These can be various realtime priorities,
    // we so need to stay root until all threads are set up.
    display->PostDaemonInit();

    display->Send();  // Clear screen.

    ft::Mutex mutex;

    // The display we expose to the user provides composite layering which can
    // be used by the UDP server.
    CompositeFlaschenTaschen layered_display(display, 16);
    layered_display.StartLayerGarbageCollection(&mutex, layer_timeout);

#ifndef __APPLE__
    // After hardware is set up, all servers are listening and all
    // threads are started with their respective priorities, we can drop
    // privileges.
    if (!drop_privs(DROP_PRIV_USER, DROP_PRIV_GROUP))
        return 1;
#endif

    udp_server_run_blocking(&layered_display, &mutex);  // last server blocks.
    delete display;
}

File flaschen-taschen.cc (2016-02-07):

// -*- mode: c++; c-basic-offset: 4; indent-tabs-mode: nil; -*-

#include <stdint.h>
#include <assert.h>

#include "clk.h"
#include "gpio.h"
#include "dma.h"
#include "pwm.h"

#include "ws2811.h"

#include "flaschen-taschen.h"

#define TARGET_FREQ   WS2811_TARGET_FREQ
#define GPIO_PIN      18
#define DMA_CHANNEL    5

#define WIDTH         8
#define HEIGHT        8

static ws2811_t ledstrings = {0};

WS2811FlaschenTaschen::WS2811FlaschenTaschen(int width, int height)
    : width_(width), height_(height) {
    const int channel = 0;
    ledstrings.freq = TARGET_FREQ;
    ledstrings.dmanum = DMA_CHANNEL;
    ledstrings.channel[channel].gpionum = GPIO_PIN;  // TODO: channel-config
    ledstrings.channel[channel].count = width * height;
    ledstrings.channel[channel].brightness = 255;
    
    assert(ws2811_init(&ledstrings) == 0);
}

WS2811FlaschenTaschen::~WS2811FlaschenTaschen() {
    ws2811_fini(&ledstrings);
}
        
void WS2811FlaschenTaschen::SetPixel(int x, int y, const Color &col) {
    if (x < 0 || x >= width() || y < 0 || y >= height())
        return;

    // Our boxes are upside down somewhat currently. Correct :)
    x = width() - x - 1;
    y = height() - y - 1;

    // Zig-zag assignment of our strips, so every other column has the
    // y-offset reverse.
    int y_off = y % height_;
    int pos = (x * height_) + ((x % 2 == 0) ? y_off : (height_-1) - y_off);

    // Our strip has swapped colors.
    const ws2811_led_t strip_color = col.g << 16 | col.r << 8 | col.b;
    ledstrings.channel[0].leds[pos] = strip_color;
}

void WS2811FlaschenTaschen::Send() {
    ws2811_render(&ledstrings);
}

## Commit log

2016-02-07 o Add LPD6803 and parallel SPI implementation.
2016-02-08 o run two servers indpendently, each in their thread. o protect access to display with mutex.
2016-02-10 o Add a couple of useful functions to UDPFlaschenTaschen o add option -s to scroll image in send-image.
2016-02-11 o Mini flaschen taschen version on LED matrix.
2016-02-13 o rename ws28xx to ws2811 to not clash with ws2801
    [demo-grid.scad]
2016-02-13 o Add support for ws2801. o wire up current test-setup. Four columns: - lpd6803 2 high - ws2811 2 high, - ws2801 4 high - ws2801 2 high.
2016-02-14 o The 'on any change' hack is not needed anymore as the column assembly only sends SPI once.
2016-02-14 o Make RGB display a switchable option in Makefile. o Make call sequence of pre/post daemon() initialization in RGB matrix FlaschenTaschen more clear.
2016-02-15 o Add simple breakout to control up to 16 strips.
    [pi-adapter.kicad_pcb, pi-adapter.sch]
2016-02-15 o Break out SPI bus as well.
    [pi-adapter.kicad_pcb, pi-adapter.sch]
2016-02-16 o Add a little termination board.
    [termination.kicad_pcb, termination.sch]
2016-02-16 o Make fab generation work for multiple targets independently o Use smaller font on Termination board for git version.
    [termination.kicad_pcb]
2016-02-16 o Tweaks for the looks in 3D view.
    [termination.kicad_pcb]
2016-02-17 o Switch back to black.
2016-02-18 o make protocols switchable on the command line.
2016-02-20 o Better sequential labelling of data lines. o Improve higher current traces.
    [pi-adapter.kicad_pcb, pi-adapter.sch]
2016-02-20 o Update PCB picture.
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2016-02-20 o Bit wider power input.
    [pi-adapter.kicad_pcb]
2016-02-20 o Hide SPI header label
    [pi-adapter.kicad_pcb]
2016-02-21 o Moar copper on 5V fused (with diminishing returns)
    [pi-adapter.kicad_pcb]
2016-02-22 o Less vias where text is. o Moar copper.
    [pi-adapter.kicad_pcb, pi-adapter.sch]
2016-02-24 o Reset layer to 0 after drawing on it, in case the non-default servers get to use the display in-between. o smallish comment updates.
2016-02-25 o Doh': serial interface connection was off by one pin.
    [pi-adapter.kicad_pcb, pi-adapter.sch]
2016-02-25 o Provide convenient mapping for Pin-header names to GPIO pins.
2016-02-25 o New Layout: Only use ws2801 and LDP6803 using the new breakout board.
2016-02-26 o move display updating into separate thread; all what is does is updating. That allows for better predictability of pauses.
2016-02-27 o defer dropping privileges until all thread priorities are set. In particular the realtime thread that is bit-banging the SPI can benefit from that (some LED strips use timing to determine end of da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
2016-03-06 o Also reference Schweppes display as previous project-of-this-kind. o Link Flaschen Taschen logo back to Noisebridge wiki. o The level shifting board is now in production; change text accordingly.
2016-03-06 o Remove obsolete demo grid.
    [demo-grid.scad]
2016-03-11 o Only do the Send() in high-prio thread for the LED strip based displays (the others don't need it). We should consider merging this implementation into ColumnAssembly. o Don't use classic RGB matri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
2016-03-14 o Check completeness of argument first before opening socket.
2016-03-14 o Simplify: remove support for WS2811 as we couldn't update these in a reasonable frame rate (and we only could use one IO port anyway).
2016-03-23 o Work-around gcc bug #53119 o Link -lrt as we use a couple of symbols
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2016-03-28 o Add thermal reliefs for GND. o Add rounded corners.
    [pi-adapter.kicad_pcb, pi-adapter.sch]
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2016-05-04 o Make large FlaschenTaschen wiring setup the default.
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2016-05-07 o Rename header references for easier connecting.
    [pi-adapter.kicad_pcb, pi-adapter.sch]
2016-05-07 o Some more renaming needed.
    [pi-adapter.kicad_pcb, pi-adapter.sch]
2016-05-08 o Increase label sizes for better readability.
    [pi-adapter.kicad_pcb]
2016-05-08 o Turn around serial connector to have the gound pin on the (square) pin 1 on the header.
    [pi-adapter.kicad_pcb, pi-adapter.sch]
2016-05-10 o Add VerticalDrawText function. o Provide vertical printing in send-text.cc utility.
2016-05-14 o Move commandline parsing into game engine for simpler game implementation. o Show on screen the player connect. o Use absolute game time in game. o Don't need Timer class anymore. o Smallish cleanu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
2016-05-15 o add left/right button in keyboard controller. o share serialized struct in header file.
2016-05-15 o Simplify main README (submodules are not needed for the usual case)
2016-05-30 o Link spixels library which is the externalized part of the MultiSPI and hardware lib.
    [pi-adapter.kicad_pcb, pi-adapter.sch, termination.kicad_pcb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]
2016-06-03 o Fix timeout decision to clear frame.
2016-06-16 o Add unicode replacement character � o Add unicode for 'full block' (decimal 9608)
2016-06-17 o Initialize buffer in PostDaemonInit() to avoid ugly reset. o Update doc with comparison SD/HD terminal.
    [column-assembly.cc, main.cc]
2016-08-01 o Make head compileable on MacOS o Make the default FT_BACKEND the terminal as this is most likely the default for anyone developing demos. o Remove additional services - now the main protocol is Fla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
    [main.cc]
2016-08-06 o Add a hardware subdirectory with readme pointing to spixels. o Add a Laser-cuttable pi mounting rig.
    [pi-mounting-rig.dxf]
2016-08-06 o More documentation in the PostScript.
    [pi-mounting-rig.dxf]
2016-12-10 o RGBMatrix: determine size by default from the matrix properties unless explicitly overridden. o Remove unnecessary crate-simulation spacing code.
    Fixes #25 - there the geometry had to explicitly set to the matrix
    geometry, which now will go automatic.
    [main.cc]
2016-12-11 o Manual examples: make sure that buffers are not truncated. The UDP protocol wants the full frame at once.
2017-07-30 o Update to latest rpi-rgb-led-matrix o Always consult the sub-project makefile if something needs rebuilding.
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2019-09-29 Update submodules to latest version. (Fixing https://github.com/hzeller/rpi-rgb-led-matrix/issues/900 )
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2024-08-18 Don't include decoding time when pushing out frames.
2025-08-04 Request a minimum receive buffer size to hold a few frames.
    In particular for large displays that send a full frame in multiple
    packets, we might not be able to pick them up fast enough before
    the kernel drops UDP packets.
    Set the `SO_RCVBUF` to comfortably fit in a few full frames.
    Issues #76
2025-08-04 Fully drain video pipeline.
    The decoder might finish multiple frames after the last packet
    has been received; make sure we extract up to the last frame.

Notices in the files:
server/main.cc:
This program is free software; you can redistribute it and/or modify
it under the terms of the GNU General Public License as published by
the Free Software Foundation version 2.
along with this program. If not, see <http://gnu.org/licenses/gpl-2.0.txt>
